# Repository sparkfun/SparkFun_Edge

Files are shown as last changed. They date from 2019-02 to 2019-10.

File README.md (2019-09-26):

SparkFun Edge 2
========================================

SparkFun Edge 2

[*SparkFun Edge 2 (DEV-15420)*](https://www.sparkfun.com/products/15420)

Edge computing is here! You've probably heard of this latest entry to the long lineage of tech buzzwords like "IoT," "LoRa," and "cloud" before it, but what is “the edge” and why does it matter? The cloud is impressively powerful but all-the-time connection requires power and connectivity that may not be available. Edge computing handles discrete tasks such as determining if someone said "yes" and responds accordingly. The audio analysis is done at the edge rather than on the web. This dramatically reduces costs and complexity while limiting potential data privacy leaks.

In collaboration with Google and Ambiq, SparkFun's Edge 2 Development Board is based around the newest edge technology and is perfect for getting your feet wet with voice and even gesture recognition without relying on the distant services of other companies. The truly special feature is in the utilization of SparkFun's open-source and FCC Certified Artemis module, whose ultra-efficient ARM Cortex-M4F 48MHz (with 96MHz burst mode) processor, is spec’d to run TensorFlow Lite using only 6uA/MHz. The SparkFun Edge 2 board currently measures ~1.6mA@3V and 48MHz and can run solely on a CR2032 coin cell battery for up to 10 days. Artemis sports all the cutting edge features expected of modern microcontrollers including six configurable I2C/SPI masters, two UARTs, one I2C/SPI slave, a 15-channel 14-bit ADC, and a dedicated Bluetooth processor that supports BLE5. On top of all that the Artemis has 1MB of flash and 384KB of SRAM memory - plenty for the vast majority of applications.

On the Edge 2 you'll have built-in access to sensors, Bluetooth, I2C expansion, and GPIO inputs/outputs. To support edge computing cases like voice recognition the Edge 2 board features two MEMS microphones, an ST LIS2DH12 3-axis accelerometer on its own I2C bus, and a connector to interface to an OV7670 camera (sold separately & functionality coming soon). As TensorFlow updates their algorithms more and more features will open up for the SparkFun Edge 2. An onboard Bluetooth antenna gives the Edge 2 out-of-the-box connectivity. Also available on the board is a Qwiic connector to add I2C sensors/devices, four LEDs, and four GPIO pins. To boast the low-power capabilities of the board we've outfitted it with battery operation from the CR2032 coin cell holder. Programming the board is taken care of with an external USB-serial adapter like the Serial Basic Breakout via a serial bootloader, but for more advanced users we've also made available the JTAG programming and debugger port.

As a brave explorer of this new technology, you'll have to use some advanced concepts but don't worry. Between Ambiq Micro's Software Development Kit and our SDK Setup Guide you'll have access to plenty of examples to begin working with your hardware.

Now get out there and make something amazing with the latest machine learning technology at your very own fingertips!

Repository Contents
-------------------

* **/Documentation** - Data sheets, additional product information
* **/Firmware** - Arduino test firmware sketch
* **/Hardware** - Eagle design files (.brd, .sch)
* **/Production** - Production panel files (.brd)

Documentation
--------------
* **[Board Support Package (BSP)](https://github.com/sparkfun/SparkFun_Edge_BSP)** - Ambiq SDK Board Support Package for the SparkFun Edge.
* **[Edge Board Hookup Guide](https://learn.sparkfun.com/tutorials/sparkfun-edge-hookup-guide)** - Basic hookup guide for the SparkFun Edge.
* **[Software Development Kit (SDK) Setup Guide](https://learn.sparkfun.com/tutorials/using-sparkfun-edge-board-with-ambiq-apollo3-sdk)** - Software Development Kit for working with the SparkFun Edge.

Product Versions
----------------
* [DEV-15420](https://www.sparkfun.com/products/15420)- SparkFun Edge 2 w/ Artemis Module
* [DEV-15170](https://www.sparkfun.com/products/15170)- SparkFun Edge

Version History
---------------
* [v20](https://github.com/sparkfun/SparkFun_Edge/tree/v2.0.0) - Edge with the Artemis
* [v10](https://github.com/sparkfun/SparkFun_Edge/tree/v10) - Initial HW release

License Information
-------------------

This product is _**open source**_! 

Please review the LICENSE.md file for license information. 

If you have any questions or concerns on licensing, please contact techsupport@sparkfun.com.

Distributed as-is; no warranty is given.

- Your friends at SparkFun.

_<COLLABORATION CREDIT>_

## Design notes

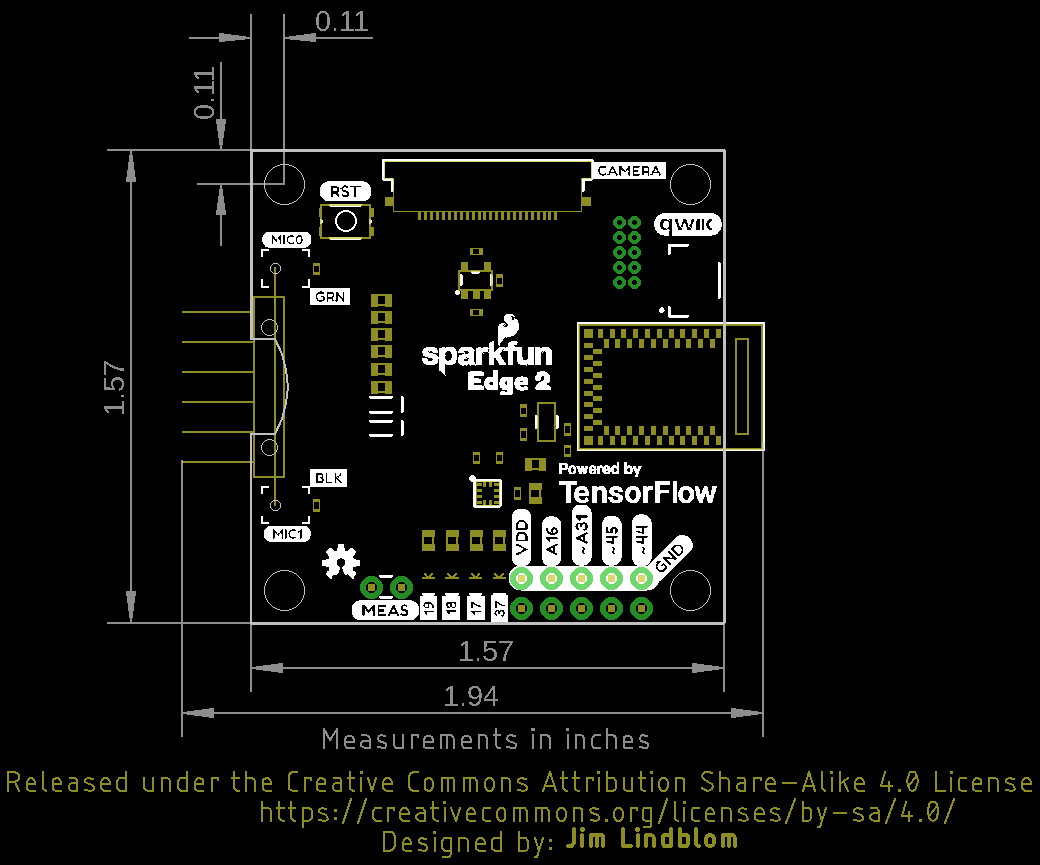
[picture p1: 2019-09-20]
Documentation/SparkFun_Edge_2_Dimensions.png

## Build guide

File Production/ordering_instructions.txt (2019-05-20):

panel size, 157x135mm
PCB thickness, 1.6mm
number of layers, 4
soldermask color, Red
silkscreen color, White
oz copper, 1oz
finish, HASL lead free
stencils, top+bottom
pcs per panel, 9
min trace width, 0.127000mm / 0.005000in
min drill size, 0.200000mm / 0.007874in
filename to layer stackup 1/2/3/4: GTL, GL2, GL3, GBL
dill files: .TXT.0102 (connect GTL to GL2)
dill files: .TXT.0115 (connect GTL to GL3)
dill files: .TXT.0116 (connect GTL to GBL)

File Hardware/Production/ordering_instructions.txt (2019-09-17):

panel size, 170x135mm
PCB thickness, 1.6mm
number of layers, 2
soldermask color, Red
silkscreen color, White
oz copper, 1oz
finish, HASL lead free
stencils, top+bottom
pcs per panel, 9
min trace width, 0.152400mm / 0.006000in
min drill size, 0.304800mm / 0.012000in

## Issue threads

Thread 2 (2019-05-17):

No MPN for 1.8V regulator on PDF schematic

cHemingway, 2019-05-17:
The 1.8V regulator, U3, does not have a part number written next to it.

I was interested to know what it was to estimate the power consumption, as it is always powered, though with disabled output by default.

nseidle, 2019-05-17:
Np. AP2127K-1.8TRG1. [Datasheet](https://www.diodes.com/assets/Datasheets/AP2127.pdf). Quiescent current looks to be 60µA.

cHemingway, 2019-05-17:
Thanks!

Closed 2019-05-17.

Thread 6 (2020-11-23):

Using Sparkfun BLE Radio for transmitting data

sleebapaul, 2020-11-23:
### Subject of the issue
I looked hard on finding a library that enables BLE communication with Sparkfun Edge. I found some Arduino libraries like `BLEPeripheral` but none of them did the job. Couldn't find any official reference for the topic either. Can somebody shed some light on this issue?

### Workbench
* Platform: Sparkfun Edge connected to MacBook Pro 2018.
* Device is powered using standard USB thorough SparkFun Serial Basic Breakout.
* I've run a micro speech example on the board and it worked well.

### Configuration

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

### Error while compiling with `BLEPeripheral` library.

```
Error while detecting libraries included by /*/*/*/Arduino/libraries/BLEPeripheral/src/BLECentral.cpp
Error while detecting libraries included by /*/*/*/Arduino/libraries/BLEPeripheral/src/EddystoneBeacon.cpp

In file included from /*/*/*/Arduino/libraries/BLEPeripheral/src/utility/lib_aci.h:34,
                 from /*/*/*/Arduino/libraries/BLEPeripheral/src/nRF8001.h:9,
                 from /*/*/*/Arduino/libraries/BLEPeripheral/src/BLEPeripheral.h:26,
                 from /*/*/*/Arduino/blutooth/blutooth.ino:3:
/*/*/*/Arduino/libraries/BLEPeripheral/src/utility/hal_platform.h:75:6: error: #error "Unsupported platform"
     #error "Unsupported platform"
```

sleebapaul, 2021-01-29:
It is so unfortunate to see the cold response from the company that built this board. A lot of enthusiasts like me, buy a SparkFun board, thinking there will be support from the community.  I'm terribly mistaken. I could've bought Arduino Nano BLE 33 and life would've been easy. Never again. Bye, SparkFun.

Closed 2021-01-29.

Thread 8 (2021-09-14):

Default Firmware

lungualexandru, 2021-09-14:
### Subject of the issue
I erased the board with a J-link programmer and haven't found the original bootloader/firmware which comes with the board.
I was wondering whether you could upload it here so that i could re-flash the board to its initial functionality.

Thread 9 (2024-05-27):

No reponse error

h-tye, 2024-05-27:
Hello, I am facing the same issue as the one referenced below. I have taken the necessary steps to ensure that the driver is not causing issues. I have also tried making my baud rate 115200. I am on Ubuntu 22.04. Any tips on how to get around this?

  All, just got my new SparkFun Edge, trying to build and flash test program, build is OK, but flashing failed.

I'm using Ubuntu 19.10. I've followed this link https://learn.sparkfun.com/tutorials/how-to-install-ch340-drivers/all#linux

So CH341 driver issue is not a problem, after plugin the USB serial to my PC, dmesg shows:

[66495.174916] usb 1-1.2: new full-speed USB device number 23 using ehci-pci
[66495.284880] usb 1-1.2: New USB device found, idVendor=1a86, idProduct=7523, bcdDevice= 2.64
[66495.284885] usb 1-1.2: New USB device strings: Mfr=0, Product=2, SerialNumber=0
[66495.284888] usb 1-1.2: Product: USB Serial
[66495.285859] ch34x 1-1.2:1.0: ch34x converter detected
[66495.287652] usb 1-1.2: ch34x converter now attached to ttyUSB3

Following this step, https://learn.sparkfun.com/tutorials/using-sparkfun-edge-board-with-ambiq-apollo3-sdk/, I tried to flash Code to Board

$ make bootload
../../../../../tools/apollo3_scripts/create_cust_image_blob.py --bin bin/example1_edge_test.bin --load-address 0xC000 --magic-num 0xCB -o bin/main_nonsecure_ota --version 0x0
Header Size =  0x80
original app_size  0x4a98 ( 19096 )
load_address  0xc000 ( 49152 )
app_size  0x4a98 ( 19096 )
w0 = 0xcb004b18
Security Value  0x10
w2 =  0x10008080
addrWord =  0xc000
versionKeyWord =  0x0
child0/feature =  0xffffffff
child1 =  0xffffffff
crc =   0xbf984a8b
Writing to file  bin/main_nonsecure_ota.bin
../../../../../tools/apollo3_scripts/create_cust_wireupdate_blob.py --load-address 0x20000 --bin bin/main_nonsecure_ota.bin -i 6 -o bin/main_nonsecure_wire --options 0x1
Header Size =  0x60
app_size  0x4b18 ( 19224 )
Writing to file  bin/main_nonsecure_wire.bin
Image from  0x0  to  0x4b18  will be loaded at 0x20000
../../../bsp/tools/uart_wired_update_sparkfun.py -b 921600 /dev/ttyUSB3 -r 1 -f bin/main_nonsecure_wire.bin -i 6
Connecting with Corvette over serial port /dev/ttyUSB3...
Sending Hello.
No response for command 0x00000000
Traceback (most recent call last):
  File "../../../bsp/tools/uart_wired_update_sparkfun.py", line 343, in <module>
    main()
  File "../../../bsp/tools/uart_wired_update_sparkfun.py", line 44, in main
    connect_device(ser)
  File "../../../bsp/tools/uart_wired_update_sparkfun.py", line 63, in connect_device
    response = send_command(hello, 88, ser)
  File "../../../bsp/tools/uart_wired_update_sparkfun.py", line 240, in send_command
    raise NoResponseError
__main__.NoResponseError
make: *** [Makefile:197: bootload] Error 1

_Originally posted by @neilengineer in https://github.com/sparkfun/SparkFun_Edge_BSP/issues/3#issuecomment-618831768_

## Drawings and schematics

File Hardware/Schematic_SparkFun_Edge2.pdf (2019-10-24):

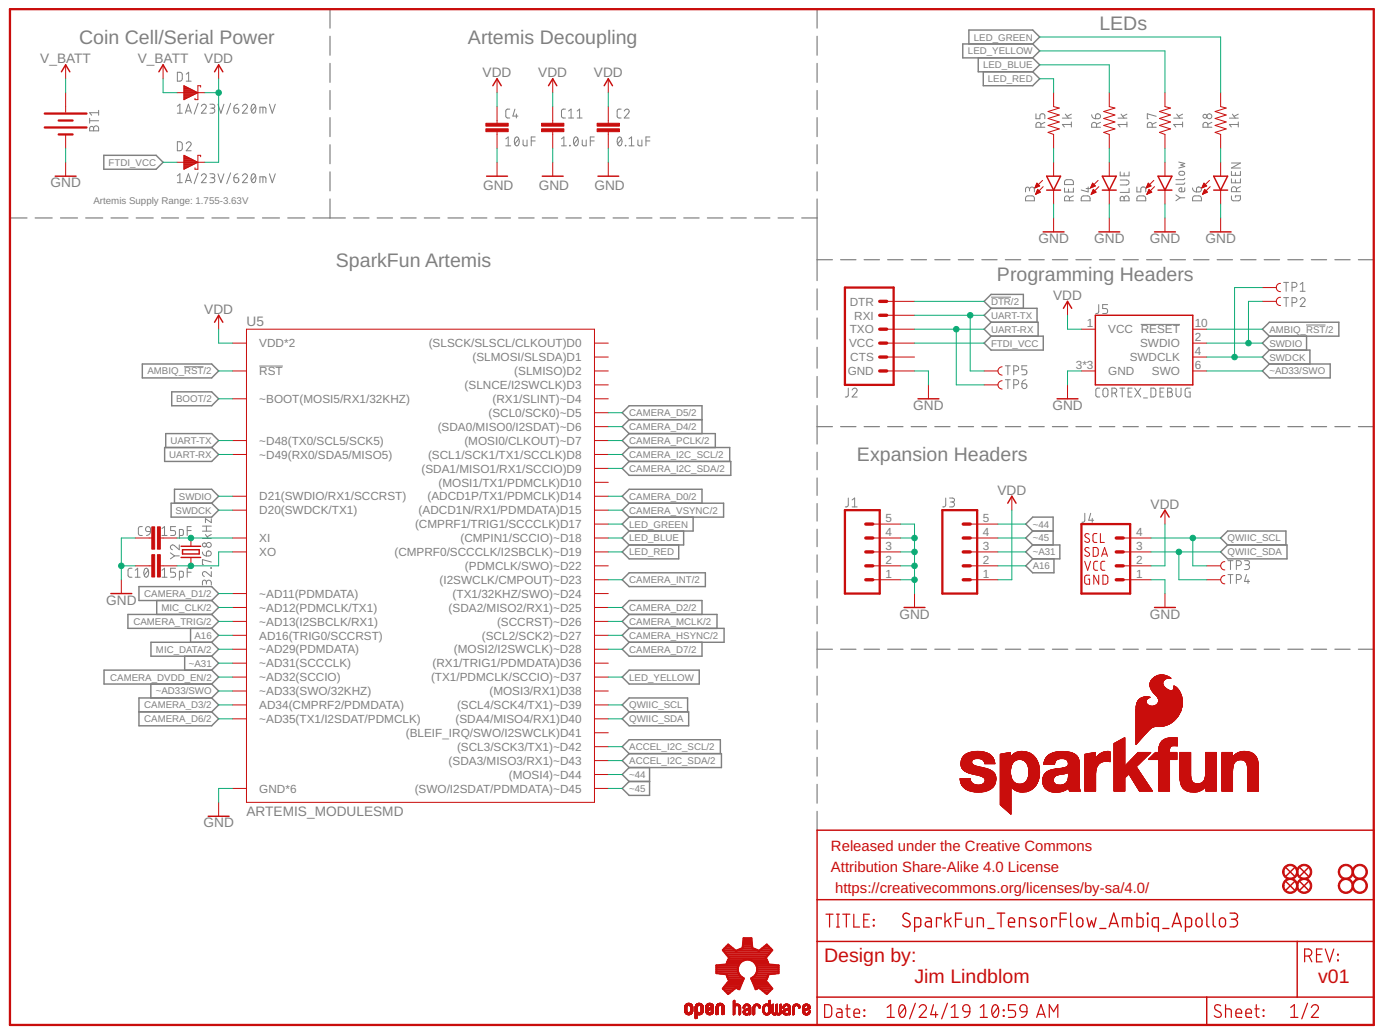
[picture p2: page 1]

~BOOT(MOSI5/RX1/32KHZ) D21(SWDIO/RX1/SCCRST) D20(SWDCK/TX1)

~AD11(PDMDATA) ~AD12(PDMCLK/TX1) ~AD13(I2SBCLK/RX1) AD16(TRIG0/SCCRST) ~AD29(PDMDATA) ~AD31(SCCCLK) ~AD32(SCCIO) AD34(CMPRF2/PDMDATA) ~AD35(TX1/I2SDAT/PDMCLK)

Released under the Creative Commons Attribution Share-Alike 4.0 License

https://creativecommons.org/licenses/by-sa/4.0/

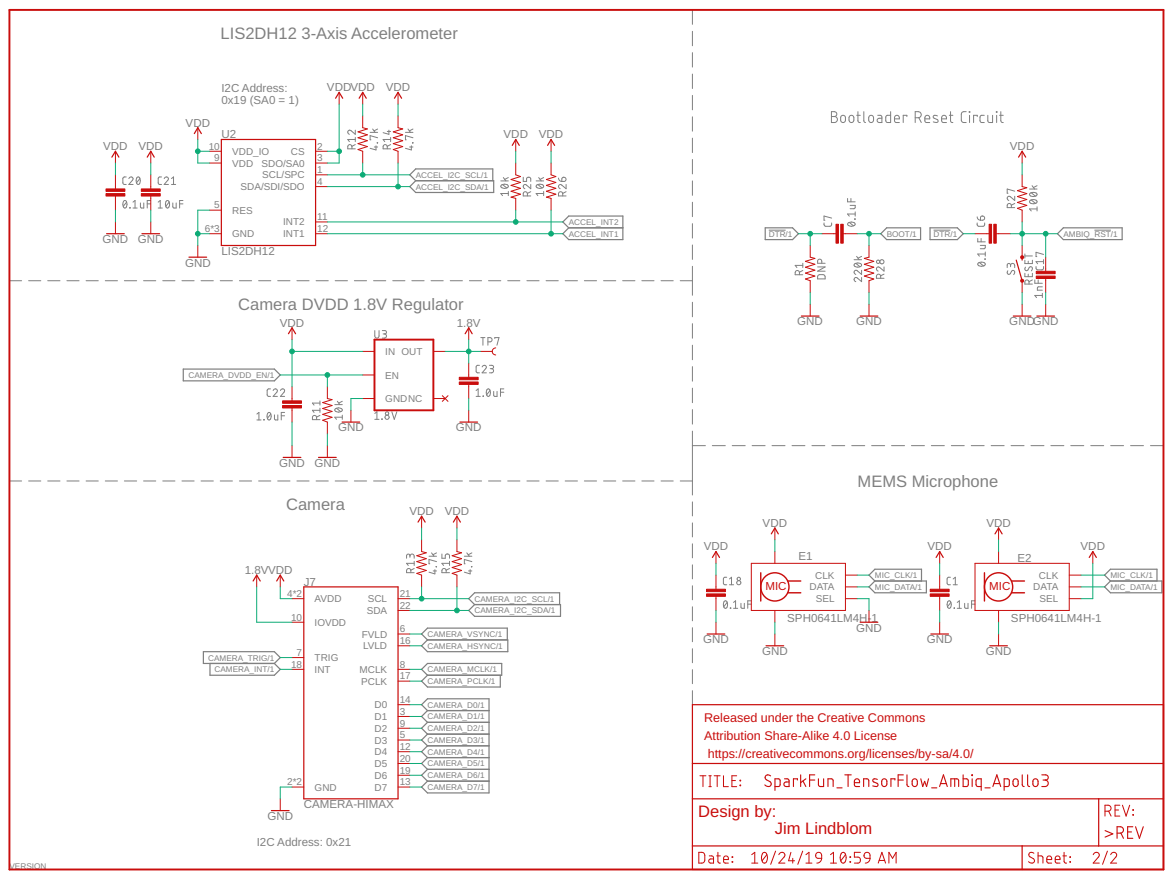
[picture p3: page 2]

Released under the Creative Commons Attribution Share-Alike 4.0 License

https://creativecommons.org/licenses/by-sa/4.0/

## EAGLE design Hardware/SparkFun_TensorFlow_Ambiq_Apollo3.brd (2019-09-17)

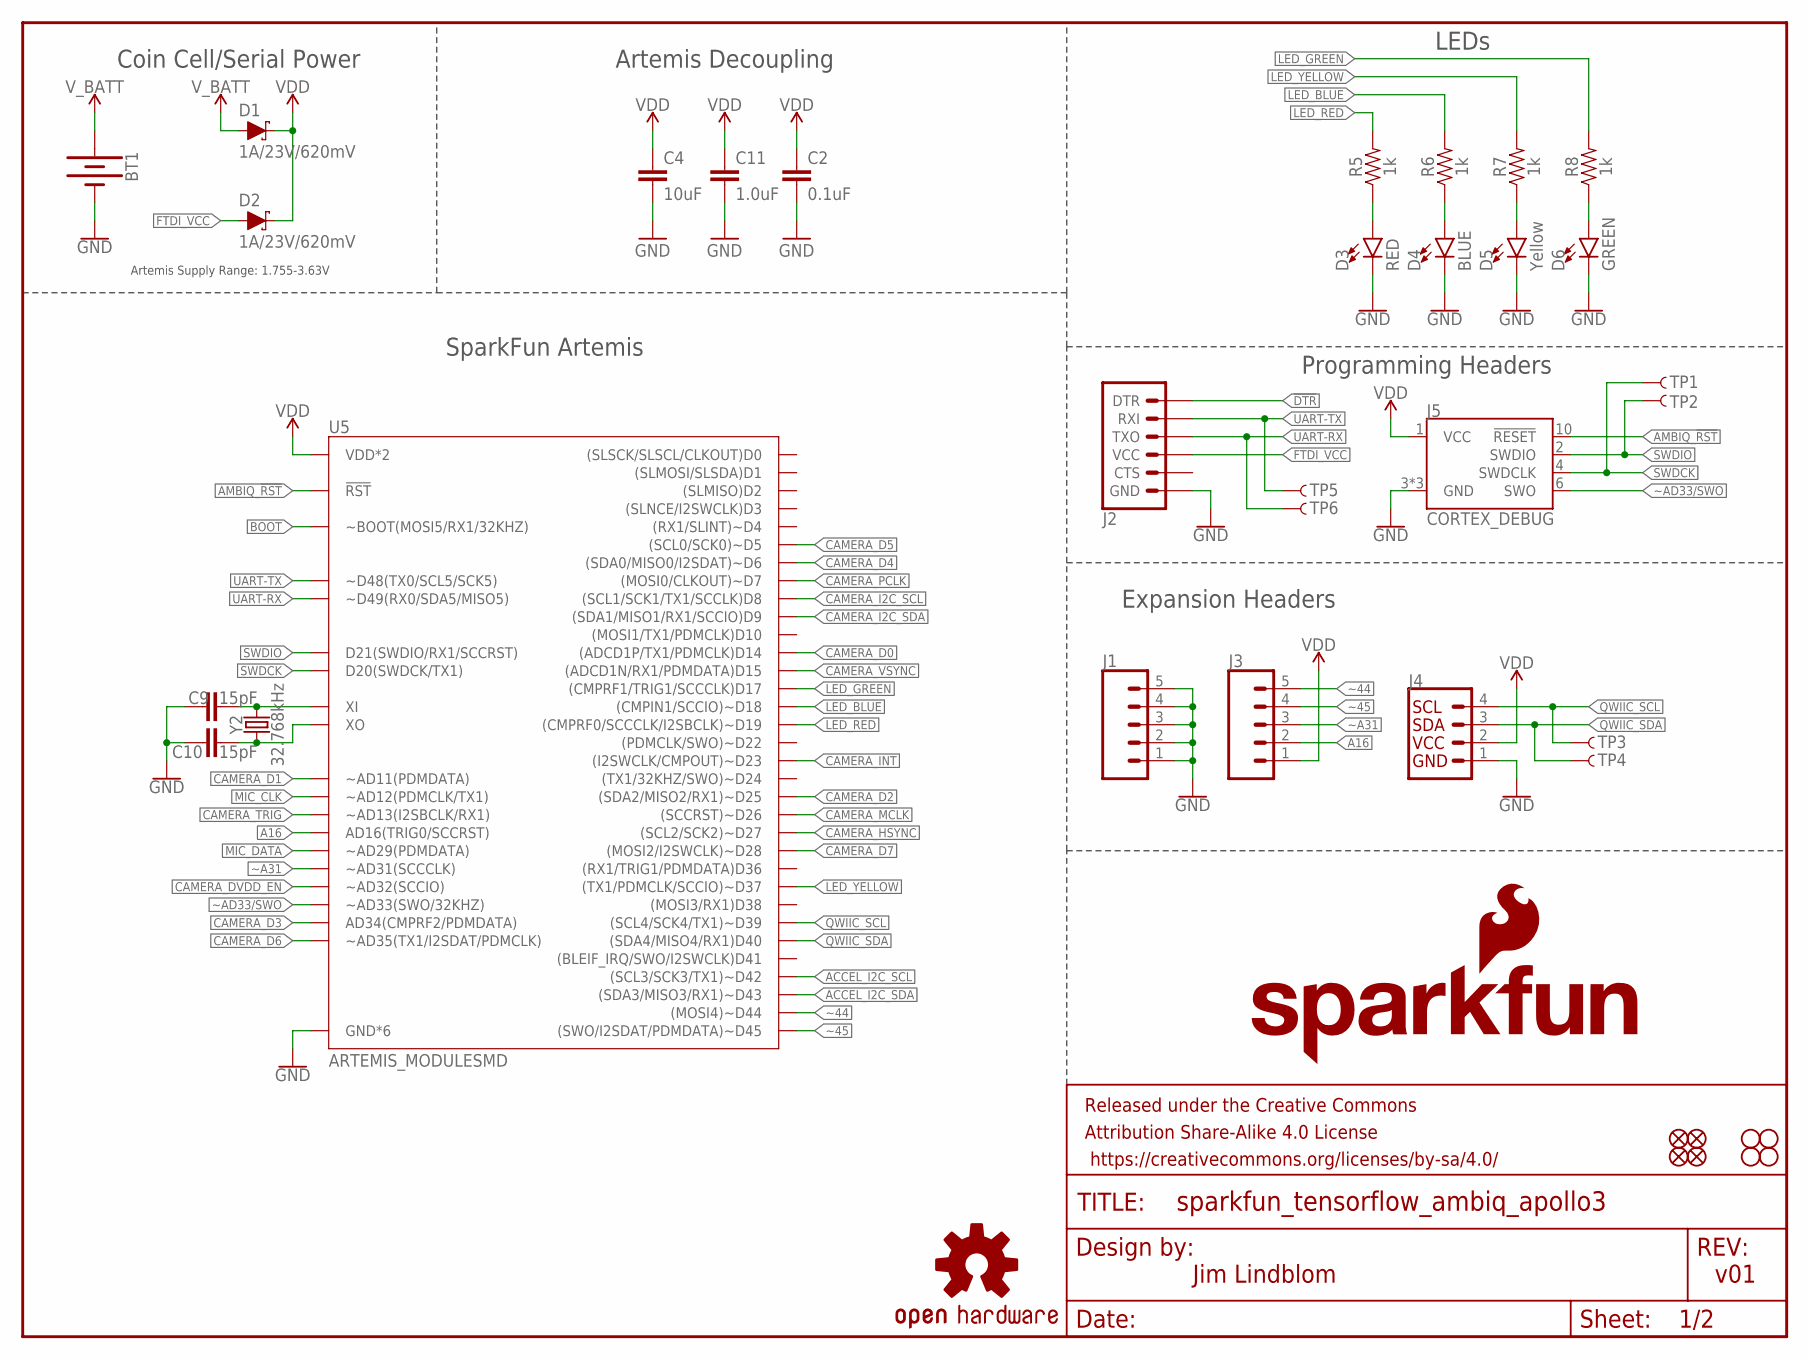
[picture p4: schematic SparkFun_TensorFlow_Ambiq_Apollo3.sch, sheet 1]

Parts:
BT1: BATTERY-20MM_SMD_4LEGS_OVERPASTE_INNER; BATTCON_20MM_4LEGS_OVERPASTE_INNER
C2: 0.1uF; 0402-TIGHT
C4: 10uF; 0603
C9, C10: 15pF; 0402-TIGHT
C11: 1.0uF; 0402-TIGHT
D1, D2: 1A/23V/620mV; SOD-323
D3: RED; LED-0603
D4: BLUE; LED-0603
D5: Yellow; LED-0603
D6: GREEN; LED-0603
FD1, FD2, FD3, FD4: FIDUCIAL1X2; FIDUCIAL-1X2
FRAME1: FRAME-LETTER; CREATIVE_COMMONS
H1, H2, H3, H4: STAND-OFF
J1, J3: CONN_05NO_SILK; 1X05_NO_SILK
J2: 6_PIN_SERIAL_TARGETSMD; 1X06-SMD_RA_MALE
J4: QWIIC_CONNECTORJS-1MM; JST04_1MM_RA
J5: CORTEX_DEBUG; 2X5-PTH-1.27MM
LOGO1: SFE_LOGO_NAME_FLAME.1_INCH; SFE_LOGO_NAME_FLAME_.1
LOGO2: OSHW-LOGOS; OSHW-LOGO-S
R5, R6, R7, R8: 1k; 0603
TP1, TP2, TP3, TP4, TP5, TP6: TEST-POINT3X5; PAD.03X.05
U5: ARTEMIS_MODULESMD; ARTEMIS_FP
Y2: 32.768kHz; CRYSTAL-SMD-3.2X1.5MM

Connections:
!DTR: J2.1 (DTR); also elsewhere on the board
A16: J3.2, U5.AD16 (AD16(TRIG0/SCCRST))
ACCEL_I2C_SCL: U5.~D42 ((SCL3/SCK3/TX1)~D42); also elsewhere on the board
ACCEL_I2C_SDA: U5.~D43 ((SDA3/MISO3/RX1)~D43); also elsewhere on the board
AMBIQ_!RST: J5.10 (!RESET), U5.~RST (!RST); also elsewhere on the board
BOOT: U5.BOOT (~BOOT(MOSI5/RX1/32KHZ)); also elsewhere on the board
CAMERA_D0: U5.D14 ((ADCD1P/TX1/PDMCLK)D14); also elsewhere on the board
CAMERA_D1: U5.~AD11 (~AD11(PDMDATA)); also elsewhere on the board
CAMERA_D2: U5.~D25 ((SDA2/MISO2/RX1)~D25); also elsewhere on the board
CAMERA_D3: U5.AD34 (AD34(CMPRF2/PDMDATA)); also elsewhere on the board
CAMERA_D4: U5.~D6 ((SDA0/MISO0/I2SDAT)~D6); also elsewhere on the board
CAMERA_D5: U5.~D5 ((SCL0/SCK0)~D5); also elsewhere on the board
CAMERA_D6: U5.~AD35 (~AD35(TX1/I2SDAT/PDMCLK)); also elsewhere on the board
CAMERA_D7: U5.~D28 ((MOSI2/I2SWCLK)~D28); also elsewhere on the board
CAMERA_DVDD_EN: U5.~AD32 (~AD32(SCCIO)); also elsewhere on the board
CAMERA_HSYNC: U5.~D27 ((SCL2/SCK2)~D27); also elsewhere on the board
CAMERA_I2C_SCL: U5.D8 ((SCL1/SCK1/TX1/SCCLK)D8); also elsewhere on the board
CAMERA_I2C_SDA: U5.D9 ((SDA1/MISO1/RX1/SCCIO)D9); also elsewhere on the board
CAMERA_INT: U5.~D23 ((I2SWCLK/CMPOUT)~D23); also elsewhere on the board
CAMERA_MCLK: U5.~D26 ((SCCRST)~D26); also elsewhere on the board
CAMERA_PCLK: U5.D7 ((MOSI0/CLKOUT)~D7); also elsewhere on the board
CAMERA_TRIG: U5.~AD13 (~AD13(I2SBCLK/RX1)); also elsewhere on the board
CAMERA_VSYNC: U5.D15 ((ADCD1N/RX1/PDMDATA)D15); also elsewhere on the board
FTDI_VCC: D2.A, J2.4 (VCC)
GND: BT1.2 (-), C2.1, C4.2, C9.1, C10.1, C11.2, D3.C, D4.C, D5.C, D6.C, J1.1, J1.2, J1.3, J1.4, J1.5, J2.6 (GND), J4.1, J5.3 (GND), J5.5 (GND), J5.9 (GND), U5.GND@1 (GND*6), U5.GND@22 (GND*6), U5.GND@38 (GND*6), U5.GND@39 (GND*6), U5.GND@47 (GND*6), U5.GND@59 (GND*6); also elsewhere on the board
LED_BLUE: R6.2, U5.~D18 ((CMPIN1/SCCIO)~D18)
LED_GREEN: R8.2, U5.D17 ((CMPRF1/TRIG1/SCCCLK)D17)
LED_RED: R5.2, U5.~D19 ((CMPRF0/SCCCLK/I2SBCLK)~D19)
LED_YELLOW: R7.2, U5.~D37 ((TX1/PDMCLK/SCCIO)~D37)
MIC_CLK: U5.~AD12 (~AD12(PDMCLK/TX1)); also elsewhere on the board
MIC_DATA: U5.~AD29 (~AD29(PDMDATA)); also elsewhere on the board
unnamed: C9.2, U5.XI, Y2.P$2 (2)
unnamed: D4.A, R6.1
unnamed: D3.A, R5.1
unnamed: D5.A, R7.1
unnamed: D6.A, R8.1
QWIIC_SCL: J4.4, TP3.P$1, U5.~D39 ((SCL4/SCK4/TX1)~D39)
QWIIC_SDA: J4.3, TP4.P$1, U5.D40 ((SDA4/MISO4/RX1)D40)
SWDCK: J5.4 (SWDCLK), TP1.P$1, U5.SWDCK (D20(SWDCK/TX1))
SWDIO: J5.2 (SWDIO), TP2.P$1, U5.SWDIO (D21(SWDIO/RX1/SCCRST))
UART-RX: J2.3 (TXO), TP6.P$1, U5.RXI-0 (~D49(RX0/SDA5/MISO5))
UART-TX: J2.2 (RXI), TP5.P$1, U5.TXO-0 (~D48(TX0/SCL5/SCK5))
VDD: C2.2, C4.1, C11.1, D1.C, D2.C, J3.1, J4.2, J5.1 (VCC), U5.VDD@36 (VDD*2), U5.VDD@37 (VDD*2); also elsewhere on the board
V_BATT: BT1.1 (+), D1.A
X0: C10.2, U5.XO, Y2.P$1 (1)
~44: J3.5, U5.~D44 ((MOSI4)~D44)
~45: J3.4, U5.~D45 ((SWO/I2SDAT/PDMDATA)~D45)
~A31: J3.3, U5.~AD31 (~AD31(SCCCLK))
~AD33/SWO: J5.6 (SWO), U5.~AD33/SWO (~AD33(SWO/32KHZ))

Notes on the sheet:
v01
Jim Lindblom
Artemis Supply Range: 1.755-3.63V
SparkFun Artemis
Coin Cell/Serial Power
Artemis Decoupling
LEDs
Programming Headers
Expansion Headers

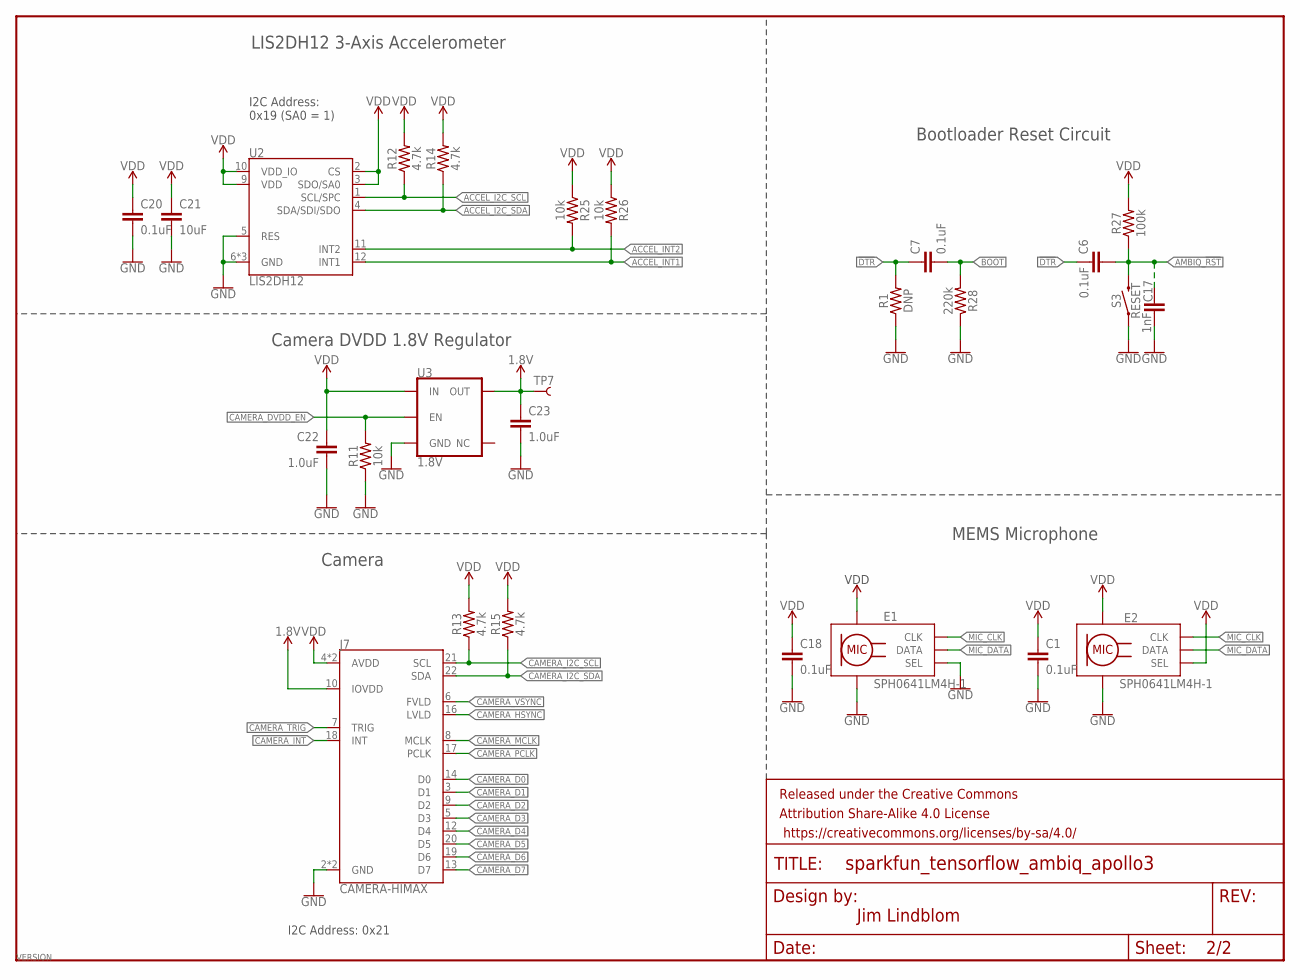
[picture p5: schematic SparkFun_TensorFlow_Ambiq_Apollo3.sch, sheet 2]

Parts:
C1, C18, C20: 0.1uF; 0402-TIGHT
C6, C7: 0.1uF; 0603
C17: 1nF; 0603
C21: 10uF; 0603
C22, C23: 1.0uF; 0402-TIGHT
E1, E2: SPH0641LM4H-1; SPH0641LM4H-1_MICROPHONE
FRAME2: FRAME-LETTERNO_PACKAGE; DUMMY
J7: CAMERA-HIMAX; FPC-24-AMPHENOL-SFV24R-1STE1HLF
R1: DNP; 0603
R11, R25, R26: 10k; 0402-TIGHT
R12, R13, R14, R15: 4.7k; 0603
R27: 100k; 0603
R28: 220k; 0603
S3: RESET; TACTILE_SWITCH_SMD_4.6X2.8MM
TP7: TEST-POINT3X5; PAD.03X.05
U2: LIS2DH12; LGA-12-LISDH12
U3: 1.8V; SOT23-5

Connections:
1.8V: C23.1, J7.10 (IOVDD), TP7.P$1, U3.5 (OUT)
!DTR: C6.1, C7.1, R1.2; also elsewhere on the board
ACCEL_I2C_SCL: R12.1, U2.1 (SCL/SPC); also elsewhere on the board
ACCEL_I2C_SDA: R14.1, U2.4 (SDA/SDI/SDO); also elsewhere on the board
ACCEL_INT1: R26.2, U2.12 (INT1)
ACCEL_INT2: R25.2, U2.11 (INT2)
AMBIQ_!RST: C6.2, C17.1, R27.1, S3.3 (2), S3.4 (2); also elsewhere on the board
BOOT: C7.2, R28.2; also elsewhere on the board
CAMERA_D0: J7.14 (D0); also elsewhere on the board
CAMERA_D1: J7.3 (D1); also elsewhere on the board
CAMERA_D2: J7.9 (D2); also elsewhere on the board
CAMERA_D3: J7.5 (D3); also elsewhere on the board
CAMERA_D4: J7.12 (D4); also elsewhere on the board
CAMERA_D5: J7.20 (D5); also elsewhere on the board
CAMERA_D6: J7.19 (D6); also elsewhere on the board
CAMERA_D7: J7.13 (D7); also elsewhere on the board
CAMERA_DVDD_EN: R11.2, U3.3 (EN); also elsewhere on the board
CAMERA_HSYNC: J7.16 (LVLD); also elsewhere on the board
CAMERA_I2C_SCL: J7.21 (SCL), R13.1; also elsewhere on the board
CAMERA_I2C_SDA: J7.22 (SDA), R15.1; also elsewhere on the board
CAMERA_INT: J7.18 (INT); also elsewhere on the board
CAMERA_MCLK: J7.8 (MCLK); also elsewhere on the board
CAMERA_PCLK: J7.17 (PCLK); also elsewhere on the board
CAMERA_TRIG: J7.7 (TRIG); also elsewhere on the board
CAMERA_VSYNC: J7.6 (FVLD); also elsewhere on the board
GND: C1.2, C17.2, C18.2, C20.2, C21.2, C22.2, C23.2, E1.2 (SEL), E1.3 (GND), E1.6 (GND), E1.7 (GND), E1.8 (GND), E2.3 (GND), E2.6 (GND), E2.7 (GND), E2.8 (GND), J7.2 (GND), J7.15 (GND), R1.1, R11.1, R28.1, S3.1, S3.2 (1), U2.5 (RES), U2.6 (GND), U2.7 (GND), U2.8 (GND), U3.2 (GND); also elsewhere on the board
MIC_CLK: E1.4 (CLK), E2.4 (CLK); also elsewhere on the board
MIC_DATA: E1.1 (DATA), E2.1 (DATA); also elsewhere on the board
VDD: C1.1, C18.1, C20.1, C21.1, C22.1, E1.5 (VDD), E2.2 (SEL), E2.5 (VDD), J7.4 (AVDD), J7.11 (AVDD), R12.2, R13.2, R14.2, R15.2, R25.1, R26.1, R27.2, U2.2 (CS), U2.3 (SDO/SA0), U2.9 (VDD), U2.10 (VDD_IO), U3.1 (IN); also elsewhere on the board

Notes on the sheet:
Camera DVDD 1.8V Regulator
LIS2DH12 3-Axis Accelerometer
Jim Lindblom
I2C Address: 0x19 (SA0 = 1)
I2C Address: 0x21
Camera
MEMS Microphone
Bootloader Reset Circuit

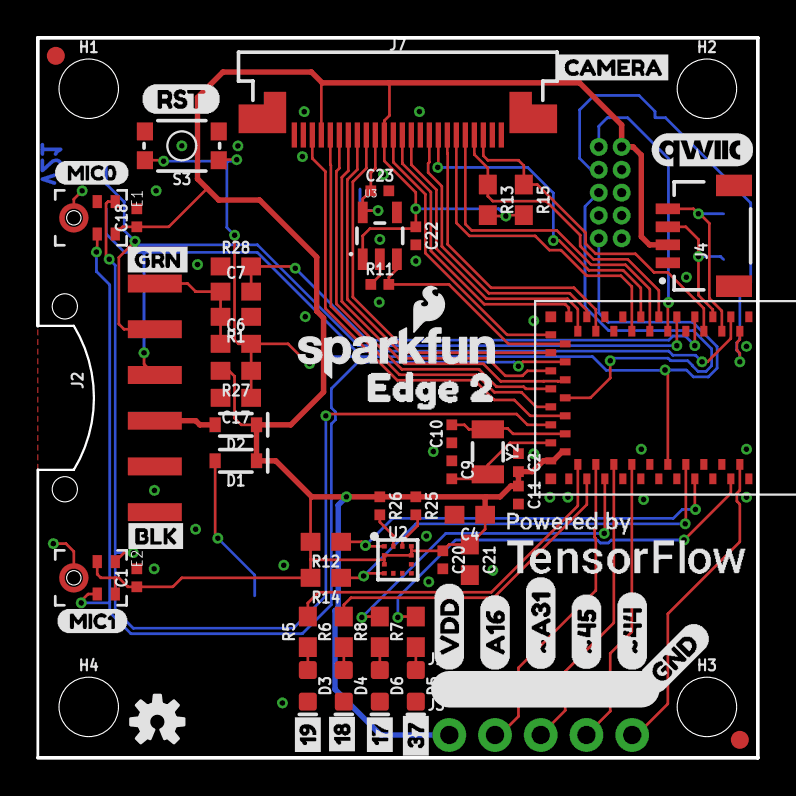
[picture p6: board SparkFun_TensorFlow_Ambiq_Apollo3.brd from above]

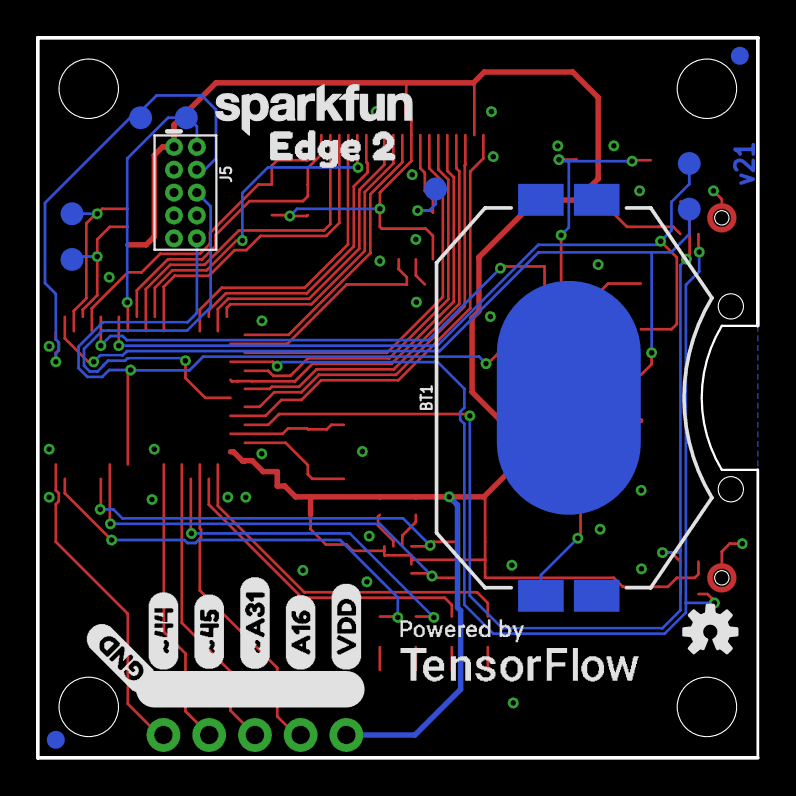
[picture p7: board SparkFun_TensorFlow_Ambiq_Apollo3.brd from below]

Board: 2 copper layers, 40.0 x 40.0 mm, 96 parts (21 on the bottom side), 52 nets.

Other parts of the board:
U$1: MIC00
U$2: BLK2
U$3, U$14: GND0
U$4, U$9: VDD1
U$5, U$12: #453
U$6, U$11: #A312
U$7, U$10: A161
U$8: MIC10
U$13, U$36: #444
U$15, U$32: EDGE_20
U$16: 372
U$19: QWIIC_COPYRIGHT_SMALL
U$20: CAMERA3
U$21, U$25: POWEREDBY_TF#JPG
U$23: 171
U$26: 182
U$27: RST15
U$28: GRN1
U$29: SFE_LOGO_NAME_.1
U$30: OSHW-LOGO-S
U$31: 193

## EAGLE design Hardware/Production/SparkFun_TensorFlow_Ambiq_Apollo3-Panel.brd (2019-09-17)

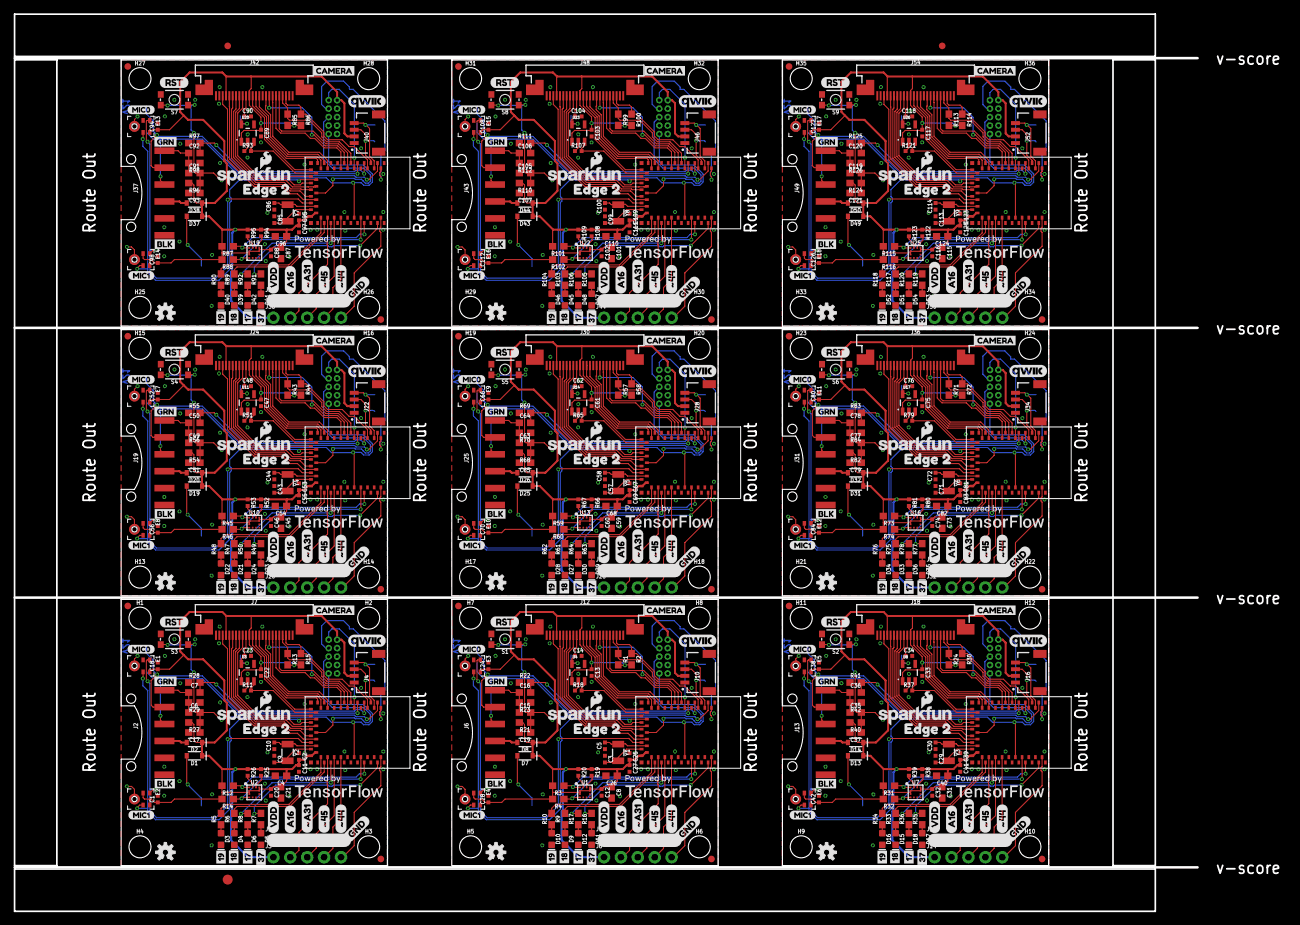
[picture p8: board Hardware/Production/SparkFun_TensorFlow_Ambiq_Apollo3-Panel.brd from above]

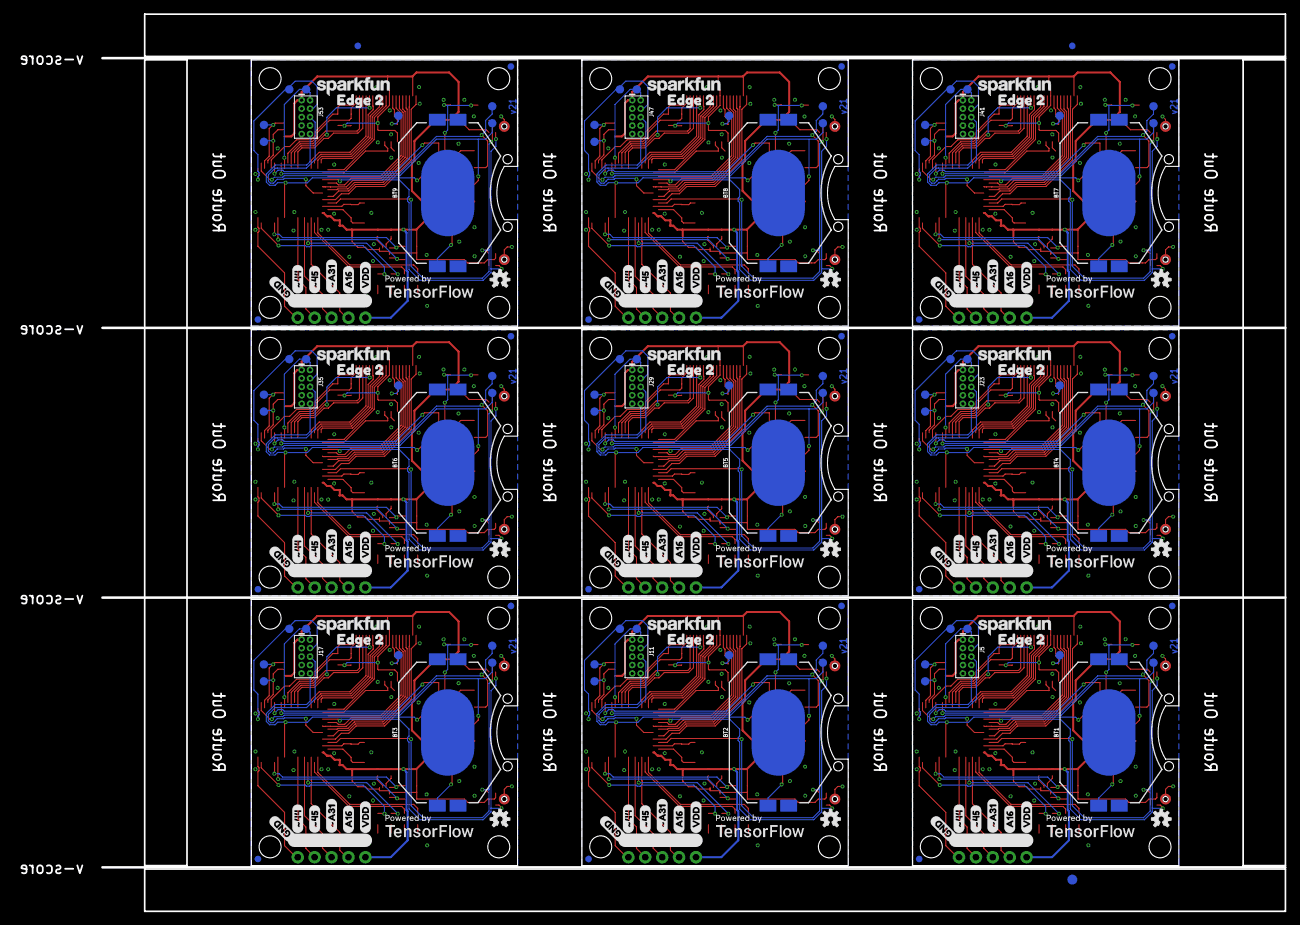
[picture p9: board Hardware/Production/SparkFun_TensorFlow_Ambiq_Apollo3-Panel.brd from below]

Board: 2 copper layers, 177.7 x 134.7 mm, 870 parts (192 on the bottom side), 468 nets.

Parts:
BT1, BT2, BT3, BT4, BT5, BT6, BT7, BT8, BT9: BATTCON_20MM_4LEGS_OVERPASTE_INNER
C1, C2, C12, C18, C20, C24, C25, C28, C32, C38, C39, C42, C46, C52, C53, C56, C60, C66, C67, C70, C74, C80, C81, C84, C88, C94, C95, C98, C102, C108, C109, C112, C116, C122, C123, C126: 0.1uF; 0402-TIGHT
C3, C5, C9, C10, C29, C30, C43, C44, C57, C58, C71, C72, C85, C86, C99, C100, C113, C114: 15pF; 0402-TIGHT
C4, C8, C21, C26, C31, C40, C45, C54, C59, C68, C73, C82, C87, C96, C101, C110, C115, C124: 10uF; 0603
C6, C15, C35, C49, C63, C77, C91, C105, C119: 0.1uF; 0603
C7, C16, C36, C50, C64, C78, C92, C106, C120: 2.2uF; 0603
C11, C13, C14, C22, C23, C27, C33, C34, C41, C47, C48, C55, C61, C62, C69, C75, C76, C83, C89, C90, C97, C103, C104, C111, C117, C118, C125: 1.0uF; 0402-TIGHT
C17, C19, C37, C51, C65, C79, C93, C107, C121: 1nF; 0603
D1, D2, D7, D8, D13, D14, D19, D20, D25, D26, D31, D32, D37, D38, D43, D44, D49, D50: 1A/23V/620mV; SOD-323
D3, D10, D16, D22, D28, D34, D40, D46, D52: RED; LED-0603
D4, D9, D15, D21, D27, D33, D39, D45, D51: BLUE; LED-0603
D5, D11, D17, D23, D29, D35, D41, D47, D53: Yellow; LED-0603
D6, D12, D18, D24, D30, D36, D42, D48, D54: GREEN; LED-0603
E1, E2, E3, E4, E5, E6, E7, E8, E9, E10, E11, E12, E13, E14, E15, E16, E17, E18: SPH0641LM4H-1; SPH0641LM4H-1_MICROPHONE
E$1, E$2, E$3, E$4: FIDUCIAL-1X2
E$5, E$6: FIDUCIAL-1.5X3
FD1, FD2, FD3, FD4, FD5, FD6, FD7, FD8, FD9, FD10, FD11, FD12, FD13, FD14, FD15, FD16, FD17, FD18, FD19, FD20, FD21, FD22, FD23, FD24, FD25, FD26, FD27, FD28, FD29, FD30, FD31, FD32, FD33, FD34, FD35, FD36: FIDUCIAL1X2; FIDUCIAL-1X2
FRAME1, FRAME3, FRAME5, FRAME7, FRAME9, FRAME11, FRAME13, FRAME15, FRAME17: FRAME-LETTER; CREATIVE_COMMONS
FRAME2, FRAME4, FRAME6, FRAME8, FRAME10, FRAME12, FRAME14, FRAME16, FRAME18: FRAME-LETTERNO_PACKAGE; DUMMY
H1, H2, H3, H4, H5, H6, H7, H8, H9, H10, H11, H12, H13, H14, H15, H16, H17, H18, H19, H20, H21, H22, H23, H24, H25, H26, H27, H28, H29, H30, H31, H32, H33, H34, H35, H36: STAND-OFF
J1, J3, J8, J9, J14, J15, J20, J21, J26, J27, J32, J33, J38, J39, J44, J45, J50, J51: 1X05_NO_SILK
J2, J6, J13, J19, J25, J31, J37, J43, J49: 1X06-SMD_RA_MALE
J4, J10, J16, J22, J28, J34, J40, J46, J52: JST04_1MM_RA
J5, J11, J17, J23, J29, J35, J41, J47, J53: CORTEX_DEBUG; 2X5-PTH-1.27MM
J7, J12, J18, J24, J30, J36, J42, J48, J54: CAMERA-HIMAX; FPC-24-AMPHENOL-SFV24R-1STE1HLF
LOGO1, LOGO3, LOGO5, LOGO7, LOGO9, LOGO11, LOGO13, LOGO15, LOGO17: SFE_LOGO_NAME_FLAME.1_INCH; SFE_LOGO_NAME_FLAME_.1
LOGO2, LOGO4, LOGO6, LOGO8, LOGO10, LOGO12, LOGO14, LOGO16, LOGO18: OSHW-LOGOS; OSHW-LOGO-S
R1, R2, R3, R4, R12, R13, R14, R15, R24, R30, R31, R32, R43, R44, R45, R46, R57, R58, R59, R60, R71, R72, R73, R74, R85, R86, R87, R88, R99, R100, R101, R102, R113, R114, R115, R116: 4.7k; 0603
R5, R6, R7, R8, R9, R10, R16, R17, R33, R34, R35, R36, R47, R48, R49, R50, R61, R62, R63, R64, R75, R76, R77, R78, R89, R90, R91, R92, R103, R104, R105, R106, R117, R118, R119, R120: 1k; 0603
R11, R18, R19, R20, R25, R26, R37, R38, R39, R51, R52, R53, R65, R66, R67, R79, R80, R81, R93, R94, R95, R107, R108, R109, R121, R122, R123: 10k; 0402-TIGHT
R21, R23, R27, R29, R40, R42, R54, R56, R68, R70, R82, R84, R96, R98, R110, R112, R124, R126: 100k; 0603
R22, R28, R41, R55, R69, R83, R97, R111, R125: 10k; 0603
S1, S2, S3, S4, S5, S6, S7, S8, S9: RESET; TACTILE_SWITCH_SMD_4.6X2.8MM
TP1, TP2, TP8, TP9, TP15, TP16, TP22, TP23, TP29, TP30, TP36, TP37, TP43, TP44, TP50, TP51, TP57, TP58: PAD.03X.05
TP3, TP4, TP5, TP6, TP7, TP10, TP11, TP12, TP13, TP14, TP17, TP18, TP19, TP20, TP21, TP24, TP25, TP26, TP27, TP28, TP31, TP32, TP33, TP34, TP35, TP38, TP39, TP40, TP41, TP42, TP45, TP46, TP47, TP48, TP49, TP52, TP53, TP54, TP55, TP56, TP59, TP60, TP61, TP62, TP63: TEST-POINT3X5; PAD.03X.05
U1, U2, U7, U10, U13, U16, U19, U22, U25: LIS2DH12; LGA-12-LISDH12
U3, U4, U8, U11, U14, U17, U20, U23, U26: 1.8V; SOT23-5
U5, U6, U9, U12, U15, U18, U21, U24, U27: ARTEMIS_MODULESMD; ARTEMIS_FP
U$1, U$41, U$70, U$99, U$128, U$157, U$186, U$215, U$244: MIC00
U$2, U$34, U$64, U$93, U$122, U$151, U$180, U$209, U$238: BLK2
U$3, U$14, U$17, U$24, U$59, U$62, U$88, U$91, U$117, U$120, U$146, U$149, U$175, U$178, U$204, U$207, U$233, U$236: GND0
U$4, U$9, U$18, U$22, U$60, U$61, U$89, U$90, U$118, U$119, U$147, U$148, U$176, U$177, U$205, U$206, U$234, U$235: VDD1
U$5, U$12, U$46, U$52, U$75, U$81, U$104, U$110, U$133, U$139, U$162, U$168, U$191, U$197, U$220, U$226, U$249, U$255: #453
U$6, U$11, U$47, U$51, U$76, U$80, U$105, U$109, U$134, U$138, U$163, U$167, U$192, U$196, U$221, U$225, U$250, U$254: #A312
U$7, U$10, U$48, U$50, U$77, U$79, U$106, U$108, U$135, U$137, U$164, U$166, U$193, U$195, U$222, U$224, U$251, U$253: A161
U$8, U$49, U$78, U$107, U$136, U$165, U$194, U$223, U$252: MIC10
U$13, U$36, U$45, U$53, U$74, U$82, U$103, U$111, U$132, U$140, U$161, U$169, U$190, U$198, U$219, U$227, U$248, U$256: #444
U$15, U$32, U$54, U$58, U$83, U$87, U$112, U$116, U$141, U$145, U$170, U$174, U$199, U$203, U$228, U$232, U$257, U$261: EDGE_20
U$16, U$37, U$66, U$95, U$124, U$153, U$182, U$211, U$240: 372
U$19, U$38, U$67, U$96, U$125, U$154, U$183, U$212, U$241: QWIIC_COPYRIGHT_SMALL
U$20, U$39, U$68, U$97, U$126, U$155, U$184, U$213, U$242: CAMERA3
U$21, U$25, U$40, U$42, U$69, U$71, U$98, U$100, U$127, U$129, U$156, U$158, U$185, U$187, U$214, U$216, U$243, U$245: POWEREDBY_TF#JPG
U$23, U$55, U$84, U$113, U$142, U$171, U$200, U$229, U$258: 171
U$26, U$56, U$85, U$114, U$143, U$172, U$201, U$230, U$259: 182
U$27, U$33, U$63, U$92, U$121, U$150, U$179, U$208, U$237: RST15
U$28, U$35, U$65, U$94, U$123, U$152, U$181, U$210, U$239: GRN1
U$29, U$43, U$72, U$101, U$130, U$159, U$188, U$217, U$246: SFE_LOGO_NAME_.1
U$30, U$44, U$73, U$102, U$131, U$160, U$189, U$218, U$247: OSHW-LOGO-S
U$31, U$57, U$86, U$115, U$144, U$173, U$202, U$231, U$260: 193
Y1, Y2, Y3, Y4, Y5, Y6, Y7, Y8, Y9: 32.768kHz; CRYSTAL-SMD-3.2X1.5MM

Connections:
1.8V: C23.1, J7.10, TP7.P$1, U3.5
1.8V1: C14.1, J12.10, TP14.P$1, U4.5
1.8V2: C34.1, J18.10, TP21.P$1, U8.5
1.8V3: C48.1, J24.10, TP28.P$1, U11.5
1.8V4: C62.1, J30.10, TP35.P$1, U14.5
1.8V5: C76.1, J36.10, TP42.P$1, U17.5
1.8V6: C90.1, J42.10, TP49.P$1, U20.5
1.8V7: C104.1, J48.10, TP56.P$1, U23.5
1.8V8: C118.1, J54.10, TP63.P$1, U26.5
!DTR: C6.1, C7.1, J2.1, R29.2
!DTR1: C15.1, C16.1, J6.1, R23.2
!DTR2: C35.1, C36.1, J13.1, R42.2
!DTR3: C49.1, C50.1, J19.1, R56.2
!DTR4: C63.1, C64.1, J25.1, R70.2
!DTR5: C77.1, C78.1, J31.1, R84.2
!DTR6: C91.1, C92.1, J37.1, R98.2
!DTR7: C105.1, C106.1, J43.1, R112.2
!DTR8: C119.1, C120.1, J49.1, R126.2
A1: J8.2, U6.AD16
A2: J14.2, U9.AD16
A3: J20.2, U12.AD16
A4: J26.2, U15.AD16
A5: J32.2, U18.AD16
A6: J38.2, U21.AD16
A7: J44.2, U24.AD16
A8: J50.2, U27.AD16
A16: J3.2, U5.AD16
ACCEL_I2C_SCL: R12.1, U2.1, U5.~D42
ACCEL_I2C_SCL1: R3.1, U1.1, U6.~D42
ACCEL_I2C_SCL2: R31.1, U7.1, U9.~D42
ACCEL_I2C_SCL3: R45.1, U10.1, U12.~D42
ACCEL_I2C_SCL4: R59.1, U13.1, U15.~D42
ACCEL_I2C_SCL5: R73.1, U16.1, U18.~D42
ACCEL_I2C_SCL6: R87.1, U19.1, U21.~D42
ACCEL_I2C_SCL7: R101.1, U22.1, U24.~D42
ACCEL_I2C_SCL8: R115.1, U25.1, U27.~D42
ACCEL_I2C_SDA: R14.1, U2.4, U5.~D43
ACCEL_I2C_SDA1: R4.1, U1.4, U6.~D43
ACCEL_I2C_SDA2: R32.1, U7.4, U9.~D43
ACCEL_I2C_SDA3: R46.1, U10.4, U12.~D43
ACCEL_I2C_SDA4: R60.1, U13.4, U15.~D43
ACCEL_I2C_SDA5: R74.1, U16.4, U18.~D43
ACCEL_I2C_SDA6: R88.1, U19.4, U21.~D43
ACCEL_I2C_SDA7: R102.1, U22.4, U24.~D43
ACCEL_I2C_SDA8: R116.1, U25.4, U27.~D43
ACCEL_INT1: R26.2, U2.12
ACCEL_INT2: R25.2, U2.11
ACCEL_INT3: R20.2, U1.12
ACCEL_INT4: R19.2, U1.11
ACCEL_INT5: R39.2, U7.12
ACCEL_INT6: R38.2, U7.11
ACCEL_INT7: R53.2, U10.12
ACCEL_INT8: R52.2, U10.11
ACCEL_INT9: R67.2, U13.12
ACCEL_INT10: R66.2, U13.11
ACCEL_INT11: R81.2, U16.12
ACCEL_INT12: R80.2, U16.11
ACCEL_INT13: R95.2, U19.12
ACCEL_INT14: R94.2, U19.11
ACCEL_INT15: R109.2, U22.12
ACCEL_INT16: R108.2, U22.11
ACCEL_INT17: R123.2, U25.12
ACCEL_INT18: R122.2, U25.11
AMBIQ_!RST: C6.2, C17.1, J5.10, R27.1, S3.3, S3.4, U5.~RST
AMBIQ_!RST1: C15.2, C19.1, J11.10, R21.1, S1.3, S1.4, U6.~RST
AMBIQ_!RST2: C35.2, C37.1, J17.10, R40.1, S2.3, S2.4, U9.~RST
AMBIQ_!RST3: C49.2, C51.1, J23.10, R54.1, S4.3, S4.4, U12.~RST
AMBIQ_!RST4: C63.2, C65.1, J29.10, R68.1, S5.3, S5.4, U15.~RST
AMBIQ_!RST5: C77.2, C79.1, J35.10, R82.1, S6.3, S6.4, U18.~RST
AMBIQ_!RST6: C91.2, C93.1, J41.10, R96.1, S7.3, S7.4, U21.~RST
AMBIQ_!RST7: C105.2, C107.1, J47.10, R110.1, S8.3, S8.4, U24.~RST
AMBIQ_!RST8: C119.2, C121.1, J53.10, R124.1, S9.3, S9.4, U27.~RST
BOOT: C7.2, R28.2, U5.BOOT
BOOT1: C16.2, R22.2, U6.BOOT
BOOT2: C36.2, R41.2, U9.BOOT
BOOT3: C50.2, R55.2, U12.BOOT
BOOT4: C64.2, R69.2, U15.BOOT
BOOT5: C78.2, R83.2, U18.BOOT
BOOT6: C92.2, R97.2, U21.BOOT
BOOT7: C106.2, R111.2, U24.BOOT
BOOT8: C120.2, R125.2, U27.BOOT
CAMERA_D0: J7.14, U5.D14
CAMERA_D1: J7.3, U5.~AD11
CAMERA_D2: J7.9, U5.~D25
CAMERA_D3: J7.5, U5.AD34
CAMERA_D4: J7.12, U5.~D6
CAMERA_D5: J7.20, U5.~D5
CAMERA_D6: J7.19, U5.~AD35
CAMERA_D7: J7.13, U5.~D28
CAMERA_D8: J12.5, U6.AD34
CAMERA_D9: J12.3, U6.~AD11
CAMERA_D10: J12.9, U6.~D25
CAMERA_D11: J12.12, U6.~D6
CAMERA_D12: J12.14, U6.D14
CAMERA_D13: J12.13, U6.~D28
CAMERA_D14: J12.19, U6.~AD35
CAMERA_D15: J12.20, U6.~D5
CAMERA_D16: J18.5, U9.AD34
CAMERA_D17: J18.3, U9.~AD11
CAMERA_D18: J18.9, U9.~D25
CAMERA_D19: J18.12, U9.~D6
CAMERA_D20: J18.14, U9.D14
CAMERA_D21: J18.13, U9.~D28
CAMERA_D22: J18.19, U9.~AD35
CAMERA_D23: J18.20, U9.~D5
CAMERA_D24: J24.5, U12.AD34
CAMERA_D25: J24.3, U12.~AD11
CAMERA_D26: J24.9, U12.~D25
CAMERA_D27: J24.12, U12.~D6
CAMERA_D28: J24.14, U12.D14
CAMERA_D29: J24.13, U12.~D28
CAMERA_D30: J24.19, U12.~AD35
CAMERA_D31: J24.20, U12.~D5
CAMERA_D32: J30.5, U15.AD34
CAMERA_D33: J30.3, U15.~AD11
CAMERA_D34: J30.9, U15.~D25
CAMERA_D35: J30.12, U15.~D6
CAMERA_D36: J30.14, U15.D14
CAMERA_D37: J30.13, U15.~D28
CAMERA_D38: J30.19, U15.~AD35
CAMERA_D39: J30.20, U15.~D5
CAMERA_D40: J36.5, U18.AD34
CAMERA_D41: J36.3, U18.~AD11
CAMERA_D42: J36.9, U18.~D25
CAMERA_D43: J36.12, U18.~D6
CAMERA_D44: J36.14, U18.D14
CAMERA_D45: J36.13, U18.~D28
CAMERA_D46: J36.19, U18.~AD35
CAMERA_D47: J36.20, U18.~D5
CAMERA_D48: J42.5, U21.AD34
CAMERA_D49: J42.3, U21.~AD11
CAMERA_D50: J42.9, U21.~D25
CAMERA_D51: J42.12, U21.~D6
CAMERA_D52: J42.14, U21.D14
CAMERA_D53: J42.13, U21.~D28
CAMERA_D54: J42.19, U21.~AD35
CAMERA_D55: J42.20, U21.~D5
CAMERA_D56: J48.5, U24.AD34
CAMERA_D57: J48.3, U24.~AD11
CAMERA_D58: J48.9, U24.~D25
CAMERA_D59: J48.12, U24.~D6
CAMERA_D60: J48.14, U24.D14
CAMERA_D61: J48.13, U24.~D28
CAMERA_D62: J48.19, U24.~AD35
CAMERA_D63: J48.20, U24.~D5
CAMERA_D64: J54.5, U27.AD34
CAMERA_D65: J54.3, U27.~AD11
CAMERA_D66: J54.9, U27.~D25
CAMERA_D67: J54.12, U27.~D6
CAMERA_D68: J54.14, U27.D14
CAMERA_D69: J54.13, U27.~D28
CAMERA_D70: J54.19, U27.~AD35
CAMERA_D71: J54.20, U27.~D5
CAMERA_DVDD_EN: R11.2, U3.3, U5.~AD32
CAMERA_DVDD_EN1: R18.2, U4.3, U6.~AD32
CAMERA_DVDD_EN2: R37.2, U8.3, U9.~AD32
CAMERA_DVDD_EN3: R51.2, U11.3, U12.~AD32
CAMERA_DVDD_EN4: R65.2, U14.3, U15.~AD32
CAMERA_DVDD_EN5: R79.2, U17.3, U18.~AD32
CAMERA_DVDD_EN6: R93.2, U20.3, U21.~AD32
CAMERA_DVDD_EN7: R107.2, U23.3, U24.~AD32
CAMERA_DVDD_EN8: R121.2, U26.3, U27.~AD32
CAMERA_HSYNC: J7.16, U5.~D27
CAMERA_HSYNC1: J12.16, U6.~D27
CAMERA_HSYNC2: J18.16, U9.~D27
CAMERA_HSYNC3: J24.16, U12.~D27
CAMERA_HSYNC4: J30.16, U15.~D27
CAMERA_HSYNC5: J36.16, U18.~D27
CAMERA_HSYNC6: J42.16, U21.~D27
CAMERA_HSYNC7: J48.16, U24.~D27
CAMERA_HSYNC8: J54.16, U27.~D27
CAMERA_I2C_SCL: J7.21, R13.1, U5.D8
CAMERA_I2C_SCL1: J12.21, R1.1, U6.D8
CAMERA_I2C_SCL2: J18.21, R24.1, U9.D8
CAMERA_I2C_SCL3: J24.21, R43.1, U12.D8
CAMERA_I2C_SCL4: J30.21, R57.1, U15.D8
CAMERA_I2C_SCL5: J36.21, R71.1, U18.D8
CAMERA_I2C_SCL6: J42.21, R85.1, U21.D8
CAMERA_I2C_SCL7: J48.21, R99.1, U24.D8
CAMERA_I2C_SCL8: J54.21, R113.1, U27.D8
CAMERA_I2C_SDA: J7.22, R15.1, U5.D9
CAMERA_I2C_SDA1: J12.22, R2.1, U6.D9
CAMERA_I2C_SDA2: J18.22, R30.1, U9.D9
CAMERA_I2C_SDA3: J24.22, R44.1, U12.D9
CAMERA_I2C_SDA4: J30.22, R58.1, U15.D9
CAMERA_I2C_SDA5: J36.22, R72.1, U18.D9
CAMERA_I2C_SDA6: J42.22, R86.1, U21.D9
CAMERA_I2C_SDA7: J48.22, R100.1, U24.D9
CAMERA_I2C_SDA8: J54.22, R114.1, U27.D9
CAMERA_INT: J7.18, U5.~D23
CAMERA_INT1: J12.18, U6.~D23
CAMERA_INT2: J18.18, U9.~D23
CAMERA_INT3: J24.18, U12.~D23
CAMERA_INT4: J30.18, U15.~D23
CAMERA_INT5: J36.18, U18.~D23
CAMERA_INT6: J42.18, U21.~D23
CAMERA_INT7: J48.18, U24.~D23
CAMERA_INT8: J54.18, U27.~D23
CAMERA_MCLK: J7.8, U5.~D26
CAMERA_MCLK1: J12.8, U6.~D26
CAMERA_MCLK2: J18.8, U9.~D26
CAMERA_MCLK3: J24.8, U12.~D26
CAMERA_MCLK4: J30.8, U15.~D26
CAMERA_MCLK5: J36.8, U18.~D26
CAMERA_MCLK6: J42.8, U21.~D26
CAMERA_MCLK7: J48.8, U24.~D26
CAMERA_MCLK8: J54.8, U27.~D26
CAMERA_PCLK: J7.17, U5.D7
CAMERA_PCLK1: J12.17, U6.D7
CAMERA_PCLK2: J18.17, U9.D7
CAMERA_PCLK3: J24.17, U12.D7
CAMERA_PCLK4: J30.17, U15.D7
CAMERA_PCLK5: J36.17, U18.D7
CAMERA_PCLK6: J42.17, U21.D7
CAMERA_PCLK7: J48.17, U24.D7
CAMERA_PCLK8: J54.17, U27.D7
CAMERA_TRIG: J7.7, U5.~AD13
CAMERA_TRIG1: J12.7, U6.~AD13
CAMERA_TRIG2: J18.7, U9.~AD13
CAMERA_TRIG3: J24.7, U12.~AD13
CAMERA_TRIG4: J30.7, U15.~AD13
CAMERA_TRIG5: J36.7, U18.~AD13
CAMERA_TRIG6: J42.7, U21.~AD13
CAMERA_TRIG7: J48.7, U24.~AD13
CAMERA_TRIG8: J54.7, U27.~AD13
CAMERA_VSYNC: J7.6, U5.D15
CAMERA_VSYNC1: J12.6, U6.D15
CAMERA_VSYNC2: J18.6, U9.D15
CAMERA_VSYNC3: J24.6, U12.D15
CAMERA_VSYNC4: J30.6, U15.D15
CAMERA_VSYNC5: J36.6, U18.D15
CAMERA_VSYNC6: J42.6, U21.D15
CAMERA_VSYNC7: J48.6, U24.D15
CAMERA_VSYNC8: J54.6, U27.D15
FTDI_VCC: D2.A, J2.4
FTDI_VCC1: D8.A, J6.4
FTDI_VCC2: D14.A, J13.4
FTDI_VCC3: D20.A, J19.4
FTDI_VCC4: D26.A, J25.4
FTDI_VCC5: D32.A, J31.4
FTDI_VCC6: D38.A, J37.4
FTDI_VCC7: D44.A, J43.4
FTDI_VCC8: D50.A, J49.4
GND: BT1.2, C1.2, C2.1, C4.2, C9.1, C10.1, C11.2, C17.2, C18.2, C20.2, C21.2, C22.2, C23.2, D3.C, D4.C, D5.C, D6.C, E1.2, E1.3, E1.6, E1.7, E1.8, E2.3, E2.6, E2.7, E2.8, J1.1, J1.2, J1.3, J1.4, J1.5, J2.6, J4.1, J5.3, J5.5, J5.9, J7.2, J7.15, R11.1, R28.1, R29.1, S3.1, S3.2, U2.5, U2.6, U2.7, U2.8, U3.2, U5.GND@1, U5.GND@22, U5.GND@38, U5.GND@39, U5.GND@47, U5.GND@59
GND1: BT2.2, C3.1, C5.1, C8.2, C12.2, C13.2, C14.2, C19.2, C24.2, C25.1, C26.2, C27.2, C28.2, D9.C, D10.C, D11.C, D12.C, E3.2, E3.3, E3.6, E3.7, E3.8, E4.3, E4.6, E4.7, E4.8, J6.6, J9.1, J9.2, J9.3, J9.4, J9.5, J10.1, J11.3, J11.5, J11.9, J12.2, J12.15, R18.1, R22.1, R23.1, S1.1, S1.2, U1.5, U1.6, U1.7, U1.8, U4.2, U6.GND@1, U6.GND@22, U6.GND@38, U6.GND@39, U6.GND@47, U6.GND@59
GND2: BT3.2, C29.1, C30.1, C31.2, C32.2, C33.2, C34.2, C37.2, C38.2, C39.1, C40.2, C41.2, C42.2, D15.C, D16.C, D17.C, D18.C, E5.2, E5.3, E5.6, E5.7, E5.8, E6.3, E6.6, E6.7, E6.8, J13.6, J15.1, J15.2, J15.3, J15.4, J15.5, J16.1, J17.3, J17.5, J17.9, J18.2, J18.15, R37.1, R41.1, R42.1, S2.1, S2.2, U7.5, U7.6, U7.7, U7.8, U8.2, U9.GND@1, U9.GND@22, U9.GND@38, U9.GND@39, U9.GND@47, U9.GND@59
GND3: BT4.2, C43.1, C44.1, C45.2, C46.2, C47.2, C48.2, C51.2, C52.2, C53.1, C54.2, C55.2, C56.2, D21.C, D22.C, D23.C, D24.C, E7.2, E7.3, E7.6, E7.7, E7.8, E8.3, E8.6, E8.7, E8.8, J19.6, J21.1, J21.2, J21.3, J21.4, J21.5, J22.1, J23.3, J23.5, J23.9, J24.2, J24.15, R51.1, R55.1, R56.1, S4.1, S4.2, U10.5, U10.6, U10.7, U10.8, U11.2, U12.GND@1, U12.GND@22, U12.GND@38, U12.GND@39, U12.GND@47, U12.GND@59
GND4: BT5.2, C57.1, C58.1, C59.2, C60.2, C61.2, C62.2, C65.2, C66.2, C67.1, C68.2, C69.2, C70.2, D27.C, D28.C, D29.C, D30.C, E9.2, E9.3, E9.6, E9.7, E9.8, E10.3, E10.6, E10.7, E10.8, J25.6, J27.1, J27.2, J27.3, J27.4, J27.5, J28.1, J29.3, J29.5, J29.9, J30.2, J30.15, R65.1, R69.1, R70.1, S5.1, S5.2, U13.5, U13.6, U13.7, U13.8, U14.2, U15.GND@1, U15.GND@22, U15.GND@38, U15.GND@39, U15.GND@47, U15.GND@59
GND5: BT6.2, C71.1, C72.1, C73.2, C74.2, C75.2, C76.2, C79.2, C80.2, C81.1, C82.2, C83.2, C84.2, D33.C, D34.C, D35.C, D36.C, E11.2, E11.3, E11.6, E11.7, E11.8, E12.3, E12.6, E12.7, E12.8, J31.6, J33.1, J33.2, J33.3, J33.4, J33.5, J34.1, J35.3, J35.5, J35.9, J36.2, J36.15, R79.1, R83.1, R84.1, S6.1, S6.2, U16.5, U16.6, U16.7, U16.8, U17.2, U18.GND@1, U18.GND@22, U18.GND@38, U18.GND@39, U18.GND@47, U18.GND@59
GND6: BT7.2, C85.1, C86.1, C87.2, C88.2, C89.2, C90.2, C93.2, C94.2, C95.1, C96.2, C97.2, C98.2, D39.C, D40.C, D41.C, D42.C, E13.2, E13.3, E13.6, E13.7, E13.8, E14.3, E14.6, E14.7, E14.8, J37.6, J39.1, J39.2, J39.3, J39.4, J39.5, J40.1, J41.3, J41.5, J41.9, J42.2, J42.15, R93.1, R97.1, R98.1, S7.1, S7.2, U19.5, U19.6, U19.7, U19.8, U20.2, U21.GND@1, U21.GND@22, U21.GND@38, U21.GND@39, U21.GND@47, U21.GND@59
GND7: BT8.2, C99.1, C100.1, C101.2, C102.2, C103.2, C104.2, C107.2, C108.2, C109.1, C110.2, C111.2, C112.2, D45.C, D46.C, D47.C, D48.C, E15.2, E15.3, E15.6, E15.7, E15.8, E16.3, E16.6, E16.7, E16.8, J43.6, J45.1, J45.2, J45.3, J45.4, J45.5, J46.1, J47.3, J47.5, J47.9, J48.2, J48.15, R107.1, R111.1, R112.1, S8.1, S8.2, U22.5, U22.6, U22.7, U22.8, U23.2, U24.GND@1, U24.GND@22, U24.GND@38, U24.GND@39, U24.GND@47, U24.GND@59
GND8: BT9.2, C113.1, C114.1, C115.2, C116.2, C117.2, C118.2, C121.2, C122.2, C123.1, C124.2, C125.2, C126.2, D51.C, D52.C, D53.C, D54.C, E17.2, E17.3, E17.6, E17.7, E17.8, E18.3, E18.6, E18.7, E18.8, J49.6, J51.1, J51.2, J51.3, J51.4, J51.5, J52.1, J53.3, J53.5, J53.9, J54.2, J54.15, R121.1, R125.1, R126.1, S9.1, S9.2, U25.5, U25.6, U25.7, U25.8, U26.2, U27.GND@1, U27.GND@22, U27.GND@38, U27.GND@39, U27.GND@47, U27.GND@59
LED_BLUE: R6.2, U5.~D18
LED_BLUE1: R9.2, U6.~D18
LED_BLUE2: R33.2, U9.~D18
LED_BLUE3: R47.2, U12.~D18
LED_BLUE4: R61.2, U15.~D18
LED_BLUE5: R75.2, U18.~D18
LED_BLUE6: R89.2, U21.~D18
LED_BLUE7: R103.2, U24.~D18
LED_BLUE8: R117.2, U27.~D18
LED_GREEN: R8.2, U5.D17
LED_GREEN1: R17.2, U6.D17
LED_GREEN2: R36.2, U9.D17
LED_GREEN3: R50.2, U12.D17
LED_GREEN4: R64.2, U15.D17
LED_GREEN5: R78.2, U18.D17
LED_GREEN6: R92.2, U21.D17
LED_GREEN7: R106.2, U24.D17
LED_GREEN8: R120.2, U27.D17
LED_RED: R5.2, U5.~D19
LED_RED1: R10.2, U6.~D19
LED_RED2: R34.2, U9.~D19
LED_RED3: R48.2, U12.~D19
LED_RED4: R62.2, U15.~D19
LED_RED5: R76.2, U18.~D19
LED_RED6: R90.2, U21.~D19
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

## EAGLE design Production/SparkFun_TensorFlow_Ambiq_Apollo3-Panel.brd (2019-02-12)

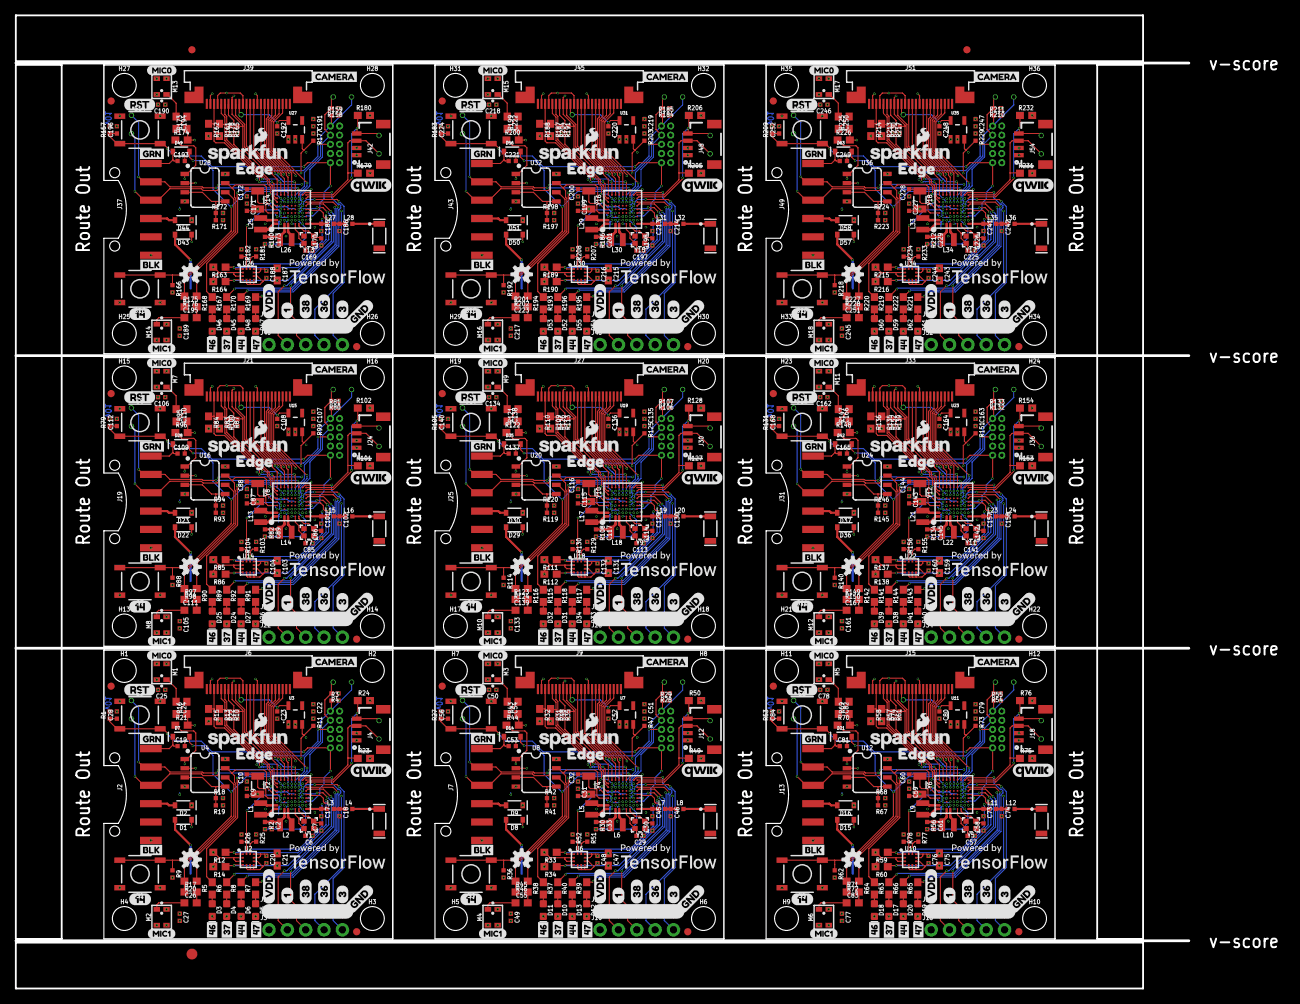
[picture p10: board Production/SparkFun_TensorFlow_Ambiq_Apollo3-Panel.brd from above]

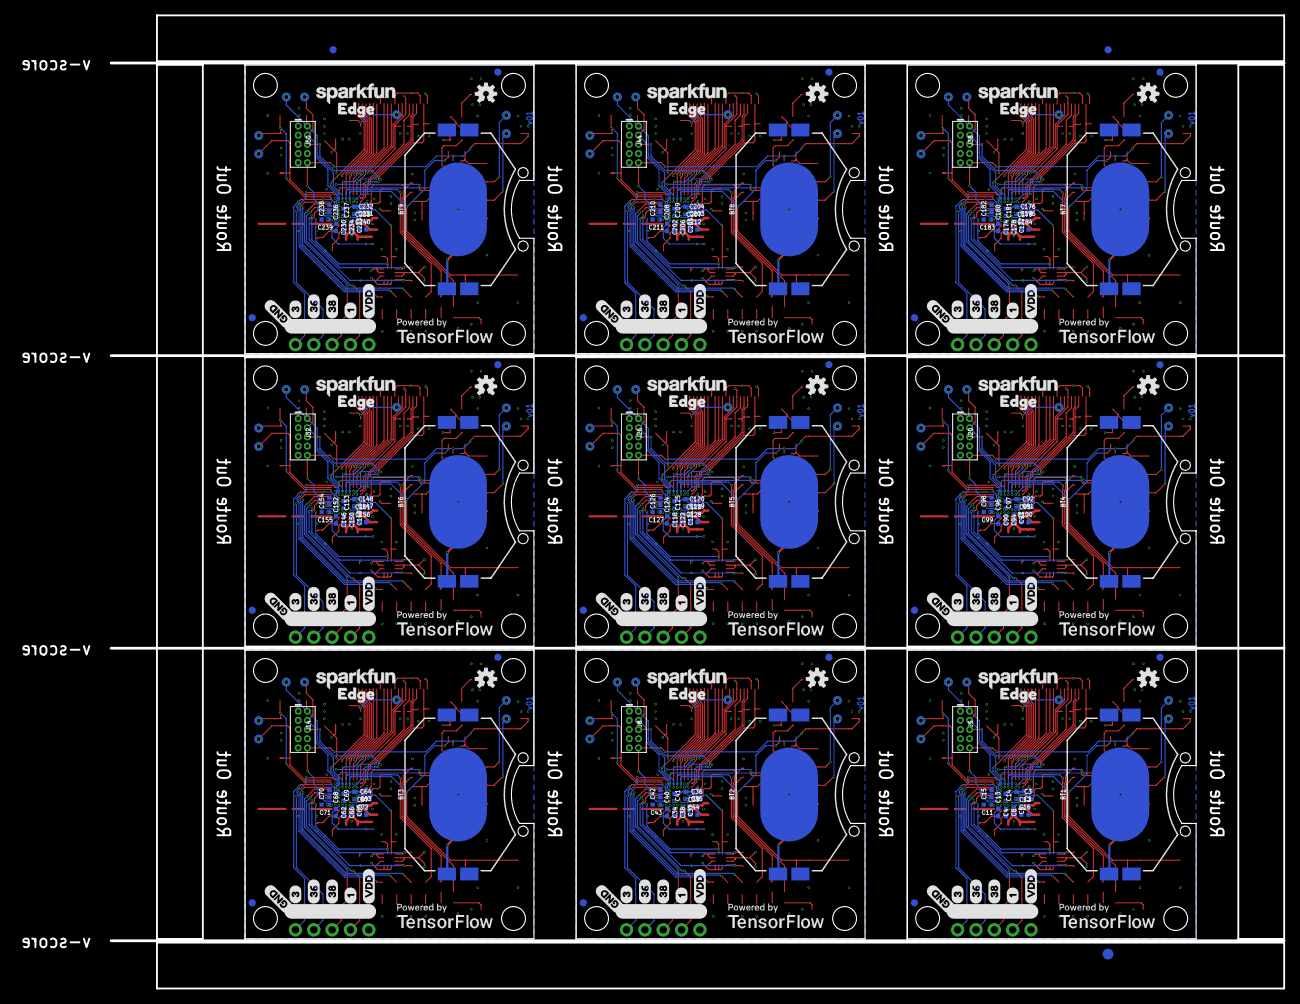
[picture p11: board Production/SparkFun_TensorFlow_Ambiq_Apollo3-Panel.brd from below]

Board: 4 copper layers, 162.4 x 134.7 mm, 1176 parts (291 on the bottom side), 666 nets.

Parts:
A1, A2, A3, A4, A5, A6, A7, A8, A9: 2.4GHZ-3.2X1.6MM; ANT-2.4GHZ-3.2X1.6X1.2MM
BT1, BT2, BT3, BT4, BT5, BT6, BT7, BT8, BT9: BATTCON_20MM_4LEGS_OVERPASTE_INNER
C1, C35, C63, C91, C119, C147, C175, C203, C231: 0.47uF; 0402-TIGHT
C2, C33, C61, C89, C117, C145, C173, C201, C229: 4.7uF; 0402-TIGHT
C3, C5, C8, C16, C36, C37, C38, C44, C64, C65, C66, C72, C92, C93, C94, C100, C120, C121, C122, C128, C148, C149, C150, C156, C176, C177, C178, C184, C204, C205, C206, C212, C232, C233, C234, C240: 2.2uF; 0402-TIGHT
C4, C12, C13, C14, C15, C22, C23, C34, C39, C40, C41, C42, C51, C52, C62, C67, C68, C69, C70, C79, C80, C90, C95, C96, C97, C98, C107, C108, C118, C123, C124, C125, C126, C135, C136, C146, C151, C152, C153, C154, C163, C164, C174, C179, C180, C181, C182, C191, C192, C202, C207, C208, C209, C210, C219, C220, C230, C235, C236, C237, C238, C247, C248: 1.0uF; 0402-TIGHT
C6, C7, C29, C30, C57, C58, C85, C86, C113, C114, C141, C142, C169, C170, C197, C198, C225, C226: 6pF; 0402-TIGHT
C9, C10, C31, C32, C59, C60, C87, C88, C115, C116, C143, C144, C171, C172, C199, C200, C227, C228: 15pF; 0402-TIGHT
C11, C43, C71, C99, C127, C155, C183, C211, C239: 47nF; 0402-TIGHT
C17, C45, C73, C101, C129, C157, C185, C213, C241: DNP; 0402-TIGHT
C18, C46, C74, C102, C130, C158, C186, C214, C242: 0.5pF; 0402-TIGHT
C19, C20, C25, C27, C48, C49, C50, C53, C76, C77, C78, C81, C104, C105, C106, C109, C132, C133, C134, C137, C160, C161, C162, C165, C188, C189, C190, C193, C216, C217, C218, C221, C244, C245, C246, C249: 0.1uF; 0402-TIGHT
C21, C47, C75, C103, C131, C159, C187, C215, C243: 10uF; 0603
C24, C26, C54, C55, C82, C83, C110, C111, C138, C139, C166, C167, C194, C195, C222, C223, C250, C251: 4.7uF; 0603
C28, C56, C84, C112, C140, C168, C196, C224, C252: 1.0nF; 0402-TIGHT
D1, D2, D8, D9, D15, D16, D22, D23, D29, D30, D36, D37, D43, D44, D50, D51, D57, D58: 1A/23V/620mV; SOD-323@1
D3, D11, D18, D25, D32, D39, D46, D53, D60: RED; LED-0603
D4, D10, D17, D24, D31, D38, D45, D52, D59: BLUE; LED-0603
D5, D12, D19, D26, D33, D40, D47, D54, D61: Yellow; LED-0603
D6, D13, D20, D27, D34, D41, D48, D55, D62: GREEN; LED-0603
D7, D14, D21, D28, D35, D42, D49, D56, D63: 250mA/100V; SOD-323
E$1, E$2, E$3, E$4: FIDUCIAL-1X2
E$5, E$6: FIDUCIAL-1.5X3
FD1, FD2, FD3, FD4, FD5, FD6, FD7, FD8, FD9, FD10, FD11, FD12, FD13, FD14, FD15, FD16, FD17, FD18, FD19, FD20, FD21, FD22, FD23, FD24, FD25, FD26, FD27, FD28, FD29, FD30, FD31, FD32, FD33, FD34, FD35, FD36: FIDUCIAL1X2; FIDUCIAL-1X2
H1, H2, H3, H4, H5, H6, H7, H8, H9, H10, H11, H12, H13, H14, H15, H16, H17, H18, H19, H20, H21, H22, H23, H24, H25, H26, H27, H28, H29, H30, H31, H32, H33, H34, H35, H36: STAND-OFF
J1, J3, J10, J11, J16, J17, J22, J23, J28, J29, J34, J35, J40, J41, J46, J47, J52, J53: 1X05_NO_SILK
J2, J7, J13, J19, J25, J31, J37, J43, J49: 1X06-SMD_RA_MALE
J4, J12, J18, J24, J30, J36, J42, J48, J54: 1X04_1MM_RA
J5, J8, J14, J20, J26, J32, J38, J44, J50: CORTEX_DEBUG_PTH; 2X5-PTH-1.27MM
J6, J9, J15, J21, J27, J33, J39, J45, J51: CAMERA-0V7670; FPC-24-AMPHENOL-SFV24R-1STE1HLF
L1, L5, L9, L13, L17, L21, L25, L29, L33: 2.2uH; 0805-WIDE
L2, L6, L10, L14, L18, L22, L26, L30, L34: 1.0uH; 0805-WIDE
L3, L7, L11, L15, L19, L23, L27, L31, L35: 2.7nH; 0402-TIGHT
L4, L8, L12, L16, L20, L24, L28, L32, L36: 2.0nH; 0402-TIGHT
LOGO1, LOGO3, LOGO5, LOGO7, LOGO9, LOGO11, LOGO13, LOGO15, LOGO17: SFE_LOGO_NAME_FLAME.1_INCH; SFE_LOGO_NAME_FLAME_.1
LOGO2, LOGO4, LOGO6, LOGO8, LOGO10, LOGO12, LOGO14, LOGO16, LOGO18: OSHW-LOGOS; OSHW-LOGO-S
M1, M2, M3, M4, M5, M6, M7, M8, M9, M10, M11, M12, M13, M14, M15, M16, M17, M18: MEMS_MIC; SPW2430HR5H-B
R1, R3, R4, R9, R10, R11, R19, R22, R25, R26, R27, R28, R29, R35, R36, R41, R47, R48, R51, R52, R53, R54, R55, R61, R62, R67, R73, R74, R77, R78, R79, R80, R81, R87, R88, R93, R99, R100, R103, R104, R105, R106, R107, R113, R114, R119, R125, R126, R129, R130, R131, R132, R133, R139, R140, R145, R151, R152, R155, R156, R157, R158, R159, R165, R166, R171, R177, R178, R181, R182, R183, R184, R185, R191, R192, R197, R203, R204, R207, R208, R209, R210, R211, R217, R218, R223, R229, R230, R233, R234: 10k; 0402-TIGHT
R2, R30, R56, R82, R108, R134, R160, R186, R212: 0; 0402-TIGHT
R5, R6, R7, R8, R37, R38, R39, R40, R63, R64, R65, R66, R89, R90, R91, R92, R115, R116, R117, R118, R141, R142, R143, R144, R167, R168, R169, R170, R193, R194, R195, R196, R219, R220, R221, R222: 1k; 0603
R12, R13, R14, R15, R23, R24, R31, R32, R33, R34, R49, R50, R57, R58, R59, R60, R75, R76, R83, R84, R85, R86, R101, R102, R109, R110, R111, R112, R127, R128, R135, R136, R137, R138, R153, R154, R161, R162, R163, R164, R179, R180, R187, R188, R189, R190, R205, R206, R213, R214, R215, R216, R231, R232: 4.7k; 0603
R16, R17, R43, R45, R69, R71, R95, R97, R121, R123, R147, R149, R173, R175, R199, R201, R225, R227: 10k; 0603
R18, R42, R68, R94, R120, R146, R172, R198, R224: 22k; 0402-TIGHT
R20, R21, R44, R46, R70, R72, R96, R98, R122, R124, R148, R150, R174, R176, R200, R202, R226, R228: 100k; 0603
S1, S2, S3, S4, S5, S6, S7, S8, S9, S10, S11, S12, S13, S14, S15, S16, S17, S18: TACTILE_SWITCH_SMD_5.2MM
TP1, TP2, TP3, TP4, TP5, TP6, TP7, TP8, TP9, TP10, TP11, TP12, TP13, TP14, TP15, TP16, TP17, TP18, TP19, TP20, TP21, TP22, TP23, TP24, TP25, TP26, TP27, TP28, TP29, TP30, TP31, TP32, TP33, TP34, TP35, TP36, TP37, TP38, TP39, TP40, TP41, TP42, TP43, TP44, TP45, TP46, TP47, TP48, TP49, TP50, TP51, TP52, TP53, TP54, TP55, TP56, TP57, TP58, TP59, TP60, TP61, TP62, TP63: TEST-POINT3X5; PAD.03X.05
U1, U5, U9, U13, U17, U21, U25, U29, U33: AMBIQ-APOLLO3KBR; BGA-81-5X5MM
U2, U6, U10, U14, U18, U22, U26, U30, U34: LIS2DH12; LGA-12-LISDH12
U3, U7, U11, U15, U19, U23, U27, U31, U35: 1.8V; SOT23-5
U4, U8, U12, U16, U20, U24, U28, U32, U36: LMV358; SO08
U$1, U$55, U$85, U$115, U$145, U$175, U$205, U$235, U$265: MIC00
U$2, U$41, U$71, U$101, U$131, U$161, U$191, U$221, U$251: BLK2
U$3, U$14, U$31, U$38, U$61, U$68, U$91, U$98, U$121, U$128, U$151, U$158, U$181, U$188, U$211, U$218, U$241, U$248: GND0
U$4, U$9, U$32, U$35, U$62, U$65, U$92, U$95, U$122, U$125, U$152, U$155, U$182, U$185, U$212, U$215, U$242, U$245: VDD1
U$5, U$8, U$43, U$44, U$73, U$74, U$103, U$104, U$133, U$134, U$163, U$164, U$193, U$194, U$223, U$224, U$253, U$254: 10
U$6, U$11, U$33, U$36, U$63, U$66, U$93, U$96, U$123, U$126, U$153, U$156, U$183, U$186, U$213, U$216, U$243, U$246: 383
U$7, U$12, U$34, U$37, U$64, U$67, U$94, U$97, U$124, U$127, U$154, U$157, U$184, U$187, U$214, U$217, U$244, U$247: 364
U$10, U$13, U$45, U$46, U$75, U$76, U$105, U$106, U$135, U$136, U$165, U$166, U$195, U$196, U$225, U$226, U$255, U$256: 31
U$15, U$47, U$77, U$107, U$137, U$167, U$197, U$227, U$257: 461
U$16, U$48, U$78, U$108, U$138, U$168, U$198, U$228, U$258: 372
U$17, U$49, U$79, U$109, U$139, U$169, U$199, U$229, U$259: 443
U$18, U$50, U$80, U$110, U$140, U$170, U$200, U$230, U$260: 470
U$19, U$51, U$81, U$111, U$141, U$171, U$201, U$231, U$261: QWIIC_COPYRIGHT_SMALL
U$20, U$52, U$82, U$112, U$142, U$172, U$202, U$232, U$262: CAMERA3
U$21, U$25, U$53, U$58, U$83, U$88, U$113, U$118, U$143, U$148, U$173, U$178, U$203, U$208, U$233, U$238, U$263, U$268: POWEREDBY_TF#JPG
U$22, U$56, U$86, U$116, U$146, U$176, U$206, U$236, U$266: MIC11
U$23, U$24, U$54, U$57, U$84, U$87, U$114, U$117, U$144, U$147, U$174, U$177, U$204, U$207, U$234, U$237, U$264, U$267: EDGE0
U$26, U$39, U$69, U$99, U$129, U$159, U$189, U$219, U$249: 1416
U$27, U$40, U$70, U$100, U$130, U$160, U$190, U$220, U$250: RST15
U$28, U$42, U$72, U$102, U$132, U$162, U$192, U$222, U$252: GRN1
U$29, U$59, U$89, U$119, U$149, U$179, U$209, U$239, U$269: SFE_LOGO_NAME_.1
U$30, U$60, U$90, U$120, U$150, U$180, U$210, U$240, U$270: OSHW-LOGO-S
Y1, Y3, Y5, Y7, Y9, Y11, Y13, Y15, Y17: 32MHz; CRYSTAL-SMD-2.0X1.6MM
Y2, Y4, Y6, Y8, Y10, Y12, Y14, Y16, Y18: 32.768kHz; CRYSTAL-SMD-3.2X1.5MM

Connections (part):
1.8V: C23.1, J6.10, TP7.P$1, U3.5
1.8V1: C52.1, J9.10, TP14.P$1, U7.5
1.8V2: C80.1, J15.10, TP21.P$1, U11.5
1.8V3: C108.1, J21.10, TP28.P$1, U15.5
1.8V4: C136.1, J27.10, TP35.P$1, U19.5
1.8V5: C164.1, J33.10, TP42.P$1, U23.5
1.8V6: C192.1, J39.10, TP49.P$1, U27.5
1.8V7: C220.1, J45.10, TP56.P$1, U31.5
1.8V8: C248.1, J51.10, TP63.P$1, U35.5
ADC_VREF: C1.1, U1.A6
ADC_VREF1: C35.1, U5.A6
ADC_VREF2: C63.1, U9.A6
ADC_VREF3: C91.1, U13.A6
ADC_VREF4: C119.1, U17.A6
ADC_VREF5: C147.1, U21.A6
ADC_VREF6: C175.1, U25.A6
ADC_VREF7: C203.1, U29.A6
ADC_VREF8: C231.1, U33.A6
AMBIQ_!RST: C19.2, C28.1, J5.10, R1.1, S2.3, S2.4, U1.G3
AMBIQ_!RST1: C53.2, C56.1, J8.10, R27.1, S4.3, S4.4, U5.G3
AMBIQ_!RST2: C81.2, C84.1, J14.10, R53.1, S6.3, S6.4, U9.G3
AMBIQ_!RST3: C109.2, C112.1, J20.10, R79.1, S8.3, S8.4, U13.G3
AMBIQ_!RST4: C137.2, C140.1, J26.10, R105.1, S10.3, S10.4, U17.G3
AMBIQ_!RST5: C165.2, C168.1, J32.10, R131.1, S12.3, S12.4, U21.G3
AMBIQ_!RST6: C193.2, C196.1, J38.10, R157.1, S14.3, S14.4, U25.G3
AMBIQ_!RST7: C221.2, C224.1, J44.10, R183.1, S16.3, S16.4, U29.G3
AMBIQ_!RST8: C249.2, C252.1, J50.10, R209.1, S18.3, S18.4, U33.G3
DTR: C19.1, D7.C, J2.1
DTR1: C53.1, D14.C, J7.1
DTR2: C81.1, D21.C, J13.1
DTR3: C109.1, D28.C, J19.1
DTR4: C137.1, D35.C, J25.1
DTR5: C165.1, D42.C, J31.1
DTR6: C193.1, D49.C, J37.1
DTR7: C221.1, D56.C, J43.1
DTR8: C249.1, D63.C, J49.1
DVDD: C11.1, U1.H3
DVDD1: C43.1, U5.H3
DVDD2: C71.1, U9.H3
DVDD3: C99.1, U13.H3
DVDD4: C127.1, U17.H3
DVDD5: C155.1, U21.H3
DVDD6: C183.1, U25.H3
DVDD7: C211.1, U29.H3
DVDD8: C239.1, U33.H3
FTDI_VCC: D2.A, J2.4
FTDI_VCC1: D9.A, J7.4
FTDI_VCC2: D16.A, J13.4
FTDI_VCC3: D23.A, J19.4
FTDI_VCC4: D30.A, J25.4
FTDI_VCC5: D37.A, J31.4
FTDI_VCC6: D44.A, J37.4
FTDI_VCC7: D51.A, J43.4
FTDI_VCC8: D58.A, J49.4
GND: BT1.2, C1.2, C2.2, C3.2, C4.2, C5.2, C6.1, C7.1, C8.2, C9.1, C10.1, C11.2, C12.2, C13.2, C14.2, C15.2, C16.2, C17.2, C18.2, C20.2, C21.2, C22.2, C23.2, C25.2, C27.2, C28.2, D3.C, D4.C, D5.C, D6.C, J1.1, J1.2, J1.3, J1.4, J1.5, J2.6, J4.1, J5.3, J5.5, J5.9, J6.2, J6.15, M1.2, M1.3, M2.2, M2.3, R4.1, R11.1, R19.1, R22.1, S1.1, S1.2, S2.1, S2.2, U1.B3, U1.C2, U1.E2, U1.E3, U1.F2, U1.H1, U1.H2, U1.J2, U2.5, U2.6, U2.7, U2.8, U3.2, U4.4
GND1: BT2.2, C29.1, C30.1, C31.1, C32.1, C33.2, C34.2, C35.2, C36.2, C37.2, C38.2, C39.2, C40.2, C41.2, C42.2, C43.2, C44.2, C45.2, C46.2, C47.2, C48.2, C49.2, C50.2, C51.2, C52.2, C56.2, D10.C, D11.C, D12.C, D13.C, J7.6, J8.3, J8.5, J8.9, J9.2, J9.15, J11.1, J11.2, J11.3, J11.4, J11.5, J12.1, M3.2, M3.3, M4.2, M4.3, R28.1, R41.1, R47.1, R48.1, S3.1, S3.2, S4.1, S4.2, U5.B3, U5.C2, U5.E2, U5.E3, U5.F2, U5.H1, U5.H2, U5.J2, U6.5, U6.6, U6.7, U6.8, U7.2, U8.4
GND2: BT3.2, C57.1, C58.1, C59.1, C60.1, C61.2, C62.2, C63.2, C64.2, C65.2, C66.2, C67.2, C68.2, C69.2, C70.2, C71.2, C72.2, C73.2, C74.2, C75.2, C76.2, C77.2, C78.2, C79.2, C80.2, C84.2, D17.C, D18.C, D19.C, D20.C, J13.6, J14.3, J14.5, J14.9, J15.2, J15.15, J17.1, J17.2, J17.3, J17.4, J17.5, J18.1, M5.2, M5.3, M6.2, M6.3, R54.1, R67.1, R73.1, R74.1, S5.1, S5.2, S6.1, S6.2, U9.B3, U9.C2, U9.E2, U9.E3, U9.F2, U9.H1, U9.H2, U9.J2, U10.5, U10.6, U10.7, U10.8, U11.2, U12.4
GND3: BT4.2, C85.1, C86.1, C87.1, C88.1, C89.2, C90.2, C91.2, C92.2, C93.2, C94.2, C95.2, C96.2, C97.2, C98.2, C99.2, C100.2, C101.2, C102.2, C103.2, C104.2, C105.2, C106.2, C107.2, C108.2, C112.2, D24.C, D25.C, D26.C, D27.C, J19.6, J20.3, J20.5, J20.9, J21.2, J21.15, J23.1, J23.2, J23.3, J23.4, J23.5, J24.1, M7.2, M7.3, M8.2, M8.3, R80.1, R93.1, R99.1, R100.1, S7.1, S7.2, S8.1, S8.2, U13.B3, U13.C2, U13.E2, U13.E3, U13.F2, U13.H1, U13.H2, U13.J2, U14.5, U14.6, U14.7, U14.8, U15.2, U16.4
GND4: BT5.2, C113.1, C114.1, C115.1, C116.1, C117.2, C118.2, C119.2, C120.2, C121.2, C122.2, C123.2, C124.2, C125.2, C126.2, C127.2, C128.2, C129.2, C130.2, C131.2, C132.2, C133.2, C134.2, C135.2, C136.2, C140.2, D31.C, D32.C, D33.C, D34.C, J25.6, J26.3, J26.5, J26.9, J27.2, J27.15, J29.1, J29.2, J29.3, J29.4, J29.5, J30.1, M9.2, M9.3, M10.2, M10.3, R106.1, R119.1, R125.1, R126.1, S9.1, S9.2, S10.1, S10.2, U17.B3, U17.C2, U17.E2, U17.E3, U17.F2, U17.H1, U17.H2, U17.J2, U18.5, U18.6, U18.7, U18.8, U19.2, U20.4
GND5: BT6.2, C141.1, C142.1, C143.1, C144.1, C145.2, C146.2, C147.2, C148.2, C149.2, C150.2, C151.2, C152.2, C153.2, C154.2, C155.2, C156.2, C157.2, C158.2, C159.2, C160.2, C161.2, C162.2, C163.2, C164.2, C168.2, D38.C, D39.C, D40.C, D41.C, J31.6, J32.3, J32.5, J32.9, J33.2, J33.15, J35.1, J35.2, J35.3, J35.4, J35.5, J36.1, M11.2, M11.3, M12.2, M12.3, R132.1, R145.1, R151.1, R152.1, S11.1, S11.2, S12.1, S12.2, U21.B3, U21.C2, U21.E2, U21.E3, U21.F2, U21.H1, U21.H2, U21.J2, U22.5, U22.6, U22.7, U22.8, U23.2, U24.4
GND6: BT7.2, C169.1, C170.1, C171.1, C172.1, C173.2, C174.2, C175.2, C176.2, C177.2, C178.2, C179.2, C180.2, C181.2, C182.2, C183.2, C184.2, C185.2, C186.2, C187.2, C188.2, C189.2, C190.2, C191.2, C192.2, C196.2, D45.C, D46.C, D47.C, D48.C, J37.6, J38.3, J38.5, J38.9, J39.2, J39.15, J41.1, J41.2, J41.3, J41.4, J41.5, J42.1, M13.2, M13.3, M14.2, M14.3, R158.1, R171.1, R177.1, R178.1, S13.1, S13.2, S14.1, S14.2, U25.B3, U25.C2, U25.E2, U25.E3, U25.F2, U25.H1, U25.H2, U25.J2, U26.5, U26.6, U26.7, U26.8, U27.2, U28.4
GND7: BT8.2, C197.1, C198.1, C199.1, C200.1, C201.2, C202.2, C203.2, C204.2, C205.2, C206.2, C207.2, C208.2, C209.2, C210.2, C211.2, C212.2, C213.2, C214.2, C215.2, C216.2, C217.2, C218.2, C219.2, C220.2, C224.2, D52.C, D53.C, D54.C, D55.C, J43.6, J44.3, J44.5, J44.9, J45.2, J45.15, J47.1, J47.2, J47.3, J47.4, J47.5, J48.1, M15.2, M15.3, M16.2, M16.3, R184.1, R197.1, R203.1, R204.1, S15.1, S15.2, S16.1, S16.2, U29.B3, U29.C2, U29.E2, U29.E3, U29.F2, U29.H1, U29.H2, U29.J2, U30.5, U30.6, U30.7, U30.8, U31.2, U32.4
GND8: BT9.2, C225.1, C226.1, C227.1, C228.1, C229.2, C230.2, C231.2, C232.2, C233.2, C234.2, C235.2, C236.2, C237.2, C238.2, C239.2, C240.2, C241.2, C242.2, C243.2, C244.2, C245.2, C246.2, C247.2, C248.2, C252.2, D59.C, D60.C, D61.C, D62.C, J49.6, J50.3, J50.5, J50.9, J51.2, J51.15, J53.1, J53.2, J53.3, J53.4, J53.5, J54.1, M17.2, M17.3, M18.2, M18.3, R210.1, R223.1, R229.1, R230.1, S17.1, S17.2, S18.1, S18.2, U33.B3, U33.C2, U33.E2, U33.E3, U33.F2, U33.H1, U33.H2, U33.J2, U34.5, U34.6, U34.7, U34.8, U35.2, U36.4
GPIO0/ACCEL_INT1: R51.2, U5.H4, U6.11
GPIO0/ACCEL_INT2: R25.2, U1.H4, U2.11
GPIO0/ACCEL_INT3: R77.2, U9.H4, U10.11
GPIO0/ACCEL_INT4: R103.2, U13.H4, U14.11
GPIO0/ACCEL_INT5: R129.2, U17.H4, U18.11
GPIO0/ACCEL_INT6: R155.2, U21.H4, U22.11
GPIO0/ACCEL_INT7: R181.2, U25.H4, U26.11
GPIO0/ACCEL_INT8: R207.2, U29.H4, U30.11
GPIO0/ACCEL_INT9: R233.2, U33.H4, U34.11
GPIO1_J3_1: J10.2, U5.G4
GPIO1_J3_2: J3.2, U1.G4
GPIO1_J3_3: J16.2, U9.G4
GPIO1_J3_4: J22.2, U13.G4
GPIO1_J3_5: J28.2, U17.G4
GPIO1_J3_6: J34.2, U21.G4
GPIO1_J3_7: J40.2, U25.G4
GPIO1_J3_8: J46.2, U29.G4
GPIO1_J3_9: J52.2, U33.G4
GPIO3_J3_1: J10.5, U5.G5
GPIO3_J3_2: J16.5, U9.G5
GPIO3_J3_3: J22.5, U13.G5
GPIO3_J3_4: J28.5, U17.G5
GPIO3_J3_5: J3.5, U1.G5
GPIO3_J3_6: J34.5, U21.G5
GPIO3_J3_7: J40.5, U25.G5
GPIO3_J3_8: J46.5, U29.G5
GPIO3_J3_9: J52.5, U33.G5
GPIO4/CAMERA_Y1: J9.18, U5.D9
GPIO4/CAMERA_Y2: J15.18, U9.D9
GPIO4/CAMERA_Y3: J21.18, U13.D9
GPIO4/CAMERA_Y4: J6.18, U1.D9
GPIO4/CAMERA_Y5: J27.18, U17.D9
GPIO4/CAMERA_Y6: J33.18, U21.D9
GPIO4/CAMERA_Y7: J39.18, U25.D9
GPIO4/CAMERA_Y8: J45.18, U29.D9
GPIO4/CAMERA_Y9: J51.18, U33.D9
GPIO5/CAMERA_Y1: J9.20, U5.E9
GPIO5/CAMERA_Y2: J15.20, U9.E9
GPIO5/CAMERA_Y3: J6.20, U1.E9
GPIO5/CAMERA_Y4: J21.20, U13.E9
GPIO5/CAMERA_Y5: J27.20, U17.E9
GPIO5/CAMERA_Y6: J33.20, U21.E9
GPIO5/CAMERA_Y7: J39.20, U25.E9
GPIO5/CAMERA_Y8: J45.20, U29.E9
GPIO5/CAMERA_Y9: J51.20, U33.E9
GPIO6/CAMERA_Y0: J6.19, U1.E8
GPIO6/CAMERA_Y1: J9.19, U5.E8
GPIO6/CAMERA_Y2: J15.19, U9.E8
GPIO6/CAMERA_Y3: J21.19, U13.E8
GPIO6/CAMERA_Y4: J27.19, U17.E8
GPIO6/CAMERA_Y5: J33.19, U21.E8
GPIO6/CAMERA_Y6: J39.19, U25.E8
GPIO6/CAMERA_Y7: J45.19, U29.E8
GPIO6/CAMERA_Y8: J51.19, U33.E8
GPIO7/CAM_XCLK: J6.13, U1.F9
GPIO7/CAM_XCLK1: J9.13, U5.F9
GPIO7/CAM_XCLK2: J15.13, U9.F9
GPIO7/CAM_XCLK3: J21.13, U13.F9
GPIO7/CAM_XCLK4: J27.13, U17.F9
GPIO7/CAM_XCLK5: J33.13, U21.F9
GPIO7/CAM_XCLK6: J39.13, U25.F9
GPIO7/CAM_XCLK7: J45.13, U29.F9
GPIO7/CAM_XCLK8: J51.13, U33.F9
GPIO8/CAMERA_Y1: J6.21, U1.F8
GPIO8/CAMERA_Y2: J9.21, U5.F8
GPIO8/CAMERA_Y3: J15.21, U9.F8
GPIO8/CAMERA_Y4: J21.21, U13.F8
GPIO8/CAMERA_Y5: J27.21, U17.F8
GPIO8/CAMERA_Y6: J33.21, U21.F8
GPIO8/CAMERA_Y7: J39.21, U25.F8
GPIO8/CAMERA_Y8: J45.21, U29.F8
GPIO8/CAMERA_Y9: J51.21, U33.F8
GPIO9/CAMERA_Y1: J9.22, U5.G7
GPIO9/CAMERA_Y2: J6.22, U1.G7
GPIO9/CAMERA_Y3: J15.22, U9.G7
GPIO9/CAMERA_Y4: J21.22, U13.G7
GPIO9/CAMERA_Y5: J27.22, U17.G7
GPIO9/CAMERA_Y6: J33.22, U21.G7
GPIO9/CAMERA_Y7: J39.22, U25.G7
GPIO9/CAMERA_Y8: J45.22, U29.G7
GPIO9/CAMERA_Y9: J51.22, U33.G7
GPIO10/CAMERA_DVDD_EN: R11.2, U1.G8, U3.3
GPIO10/CAMERA_DVDD_EN1: R47.2, U5.G8, U7.3
GPIO10/CAMERA_DVDD_EN2: R73.2, U9.G8, U11.3
GPIO10/CAMERA_DVDD_EN3: R99.2, U13.G8, U15.3
GPIO10/CAMERA_DVDD_EN4: R125.2, U17.G8, U19.3
GPIO10/CAMERA_DVDD_EN5: R151.2, U21.G8, U23.3
GPIO10/CAMERA_DVDD_EN6: R177.2, U25.G8, U27.3
GPIO10/CAMERA_DVDD_EN7: R203.2, U29.G8, U31.3
GPIO10/CAMERA_DVDD_EN8: R229.2, U33.G8, U35.3
GPIO11/MIC0: R21.1, U1.B5, U4.1
GPIO11/MIC1: R44.1, U5.B5, U8.1
GPIO11/MIC2: R70.1, U9.B5, U12.1
GPIO11/MIC3: R96.1, U13.B5, U16.1
GPIO11/MIC4: R122.1, U17.B5, U20.1
GPIO11/MIC5: R148.1, U21.B5, U24.1
GPIO11/MIC6: R174.1, U25.B5, U28.1
GPIO11/MIC7: R200.1, U29.B5, U32.1
GPIO11/MIC8: R226.1, U33.B5, U36.1
GPIO12/CAMERA_VSYNC: J6.7, U1.A7
GPIO12/CAMERA_VSYNC1: J9.7, U5.A7
GPIO12/CAMERA_VSYNC2: J15.7, U9.A7
GPIO12/CAMERA_VSYNC3: J21.7, U13.A7
GPIO12/CAMERA_VSYNC4: J27.7, U17.A7
GPIO12/CAMERA_VSYNC5: J33.7, U21.A7
GPIO12/CAMERA_VSYNC6: J39.7, U25.A7
GPIO12/CAMERA_VSYNC7: J45.7, U29.A7
GPIO12/CAMERA_VSYNC8: J51.7, U33.A7
GPIO13/CAMERA_PWDN: J6.8, R22.2, U1.B7
GPIO13/CAMERA_PWDN1: J9.8, R48.2, U5.B7
GPIO13/CAMERA_PWDN2: J15.8, R74.2, U9.B7
GPIO13/CAMERA_PWDN3: J21.8, R100.2, U13.B7
GPIO13/CAMERA_PWDN4: J27.8, R126.2, U17.B7
GPIO13/CAMERA_PWDN5: J33.8, R152.2, U21.B7
GPIO13/CAMERA_PWDN6: J39.8, R178.2, U25.B7
GPIO13/CAMERA_PWDN7: J45.8, R204.2, U29.B7
GPIO13/CAMERA_PWDN8: J51.8, R230.2, U33.B7
GPIO14/USER_BUTTON: D7.A, R9.1, S1.3, S1.4, U1.D7
GPIO14/USER_BUTTON1: D14.A, R36.1, S3.3, S3.4, U5.D7
GPIO14/USER_BUTTON2: D21.A, R62.1, S5.3, S5.4, U9.D7
GPIO14/USER_BUTTON3: D28.A, R88.1, S7.3, S7.4, U13.D7
GPIO14/USER_BUTTON4: D35.A, R114.1, S9.3, S9.4, U17.D7
GPIO14/USER_BUTTON5: D42.A, R140.1, S11.3, S11.4, U21.D7
GPIO14/USER_BUTTON6: D49.A, R166.1, S13.3, S13.4, U25.D7
GPIO14/USER_BUTTON7: D56.A, R192.1, S15.3, S15.4, U29.D7
GPIO14/USER_BUTTON8: D63.A, R218.1, S17.3, S17.4, U33.D7
GPIO15/CAMERA_RESET: J6.6, R10.1, U1.C7
GPIO15/CAMERA_RESET1: J9.6, R35.1, U5.C7
GPIO15/CAMERA_RESET2: J15.6, R61.1, U9.C7
GPIO15/CAMERA_RESET3: J21.6, R87.1, U13.C7
GPIO15/CAMERA_RESET4: J27.6, R113.1, U17.C7
GPIO15/CAMERA_RESET5: J33.6, R139.1, U21.C7
GPIO15/CAMERA_RESET6: J39.6, R165.1, U25.C7
GPIO15/CAMERA_RESET7: J45.6, R191.1, U29.C7
GPIO15/CAMERA_RESET8: J51.6, R217.1, U33.C7
GPIO17/ACCEL_INT1: R26.2, U1.D3, U2.12
GPIO17/ACCEL_INT2: R52.2, U5.D3, U6.12
GPIO17/ACCEL_INT3: R78.2, U9.D3, U10.12
GPIO17/ACCEL_INT4: R104.2, U13.D3, U14.12
GPIO17/ACCEL_INT5: R130.2, U17.D3, U18.12
GPIO17/ACCEL_INT6: R156.2, U21.D3, U22.12
GPIO17/ACCEL_INT7: R182.2, U25.D3, U26.12
GPIO17/ACCEL_INT8: R208.2, U29.D3, U30.12
GPIO17/ACCEL_INT9: R234.2, U33.D3, U34.12
GPIO20/SWDCK: J5.4, R4.2, TP1.P$1, U1.G6
GPIO20/SWDCK1: J8.4, R28.2, TP8.P$1, U5.G6
GPIO20/SWDCK2: J14.4, R54.2, TP15.P$1, U9.G6
GPIO20/SWDCK3: J20.4, R80.2, TP22.P$1, U13.G6
GPIO20/SWDCK4: J26.4, R106.2, TP29.P$1, U17.G6
GPIO20/SWDCK5: J32.4, R132.2, TP36.P$1, U21.G6
GPIO20/SWDCK6: J38.4, R158.2, TP43.P$1, U25.G6
GPIO20/SWDCK7: J44.4, R184.2, TP50.P$1, U29.G6
GPIO20/SWDCK8: J50.4, R210.2, TP57.P$1, U33.G6
GPIO21/SWDIO: J5.2, R3.1, TP2.P$1, U1.F7
GPIO21/SWDIO1: J8.2, R29.1, TP9.P$1, U5.F7
GPIO21/SWDIO2: J14.2, R55.1, TP16.P$1, U9.F7
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

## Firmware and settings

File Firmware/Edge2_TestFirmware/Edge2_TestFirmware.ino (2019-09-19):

/* Author: Nathan Seidle
  Created: Septempter 19th, 2019
  License: MIT. See SparkFun Arduino Apollo3 Project for more information

  This example demonstrates the following:
    Activate 1.8V vreg
    Ping Accel
    Ping mics
    Twinkle LEDs
    Drive Qwiic pins
*/

#include <Wire.h>

#include "SparkFun_LIS2DH12.h"

SPARKFUN_LIS2DH12 accel; //Create instance of object

#define ACCEL_ADDRESS 0x19 //On the Edge and Edge2 the accelerometer is address 0x19

unsigned long lastTimeCheck = 0;

#define QWIIC_SCL 39
#define QWIIC_SDA 30

#define VDD_CAMERA 32
#define VDD_PDM 0 //Only available on v2.2 PCB and above
#define VDD_ACCEL 41 //Only available on v2.2 PCB and above

//-=-=-= Vars for PDM -=-=-=-

//Global variables needed for PDM library
#define pdmDataBufferSize 4096 //Default is array of 4096 * 32bit
uint32_t pdmDataBuffer[pdmDataBufferSize];

//Global variables needed for the FFT in this sketch
float g_fPDMTimeDomain[pdmDataBufferSize * 2];
float g_fPDMFrequencyDomain[pdmDataBufferSize * 2];
float g_fPDMMagnitudes[pdmDataBufferSize * 2];
uint32_t sampleFreq;

//Enable these defines for additional debug printing
#define PRINT_PDM_DATA 0
#define PRINT_FFT_DATA 0

#include <PDM.h> //Include PDM library included with the Aruino_Apollo3 core
AP3_PDM myPDM; //Create instance of PDM class

//Math library needed for FFT
#define ARM_MATH_CM4
#include <arm_math.h>

//-=-=-=- End Vars for PDM -=-=-=-

bool accelGood = false;
bool micGood = false;

void setup()
{
  Serial.begin(9600);
  Serial.println("SparkFun Accel Example");

  pinMode(LED_GREEN, OUTPUT);
  pinMode(LED_RED, OUTPUT);
  pinMode(LED_YELLOW, OUTPUT);
  pinMode(LED_BLUE, OUTPUT);
  digitalWrite(LED_GREEN, LOW);
  digitalWrite(LED_RED, LOW);
  digitalWrite(LED_YELLOW, HIGH);
  digitalWrite(LED_BLUE, HIGH);

  pinMode(VDD_CAMERA, OUTPUT);
  digitalWrite(VDD_CAMERA, HIGH); //Power up camera 1.8V regulator.

  //Normally we would not drive the SDA/SCL lines directly on the Qwiic connector (Wire)
  //but the test jig is just looking for continuity
  pinMode(QWIIC_SCL, OUTPUT);
  digitalWrite(QWIIC_SCL, LOW);
  pinMode(QWIIC_SDA, OUTPUT);
  digitalWrite(QWIIC_SDA, HIGH);

  pinMode(VDD_ACCEL, OUTPUT);
  digitalWrite(VDD_ACCEL, HIGH); //Power up accel. Only available on v2.2 PCB and above.

  Wire1.begin(); //Accel is on IOM3 and defined in the variant file as Wire1.

  //By default the SparkFun library uses Wire. We need to begin
  //with Wire1 on the Edge/Edge2.
  if (accel.begin(ACCEL_ADDRESS, Wire1) == false)
  {
    Serial.println("Accelerometer not detected. Are you sure you did a Wire1.begin()? Freezing...");
    while (1);
  }

  pinMode(VDD_PDM, OUTPUT);
  digitalWrite(VDD_PDM, HIGH); //Power up mics. Only available on v2.2 PCB and above.

  if (myPDM.begin() == false) // Turn on PDM with default settings
  {
    Serial.println("PDM Init failed. Are you sure these pins are PDM capable?");
    while (1);
  }
  Serial.println("PDM Initialized");

  printPDMConfig();

  myPDM.getData(pdmDataBuffer, pdmDataBufferSize); //This clears the current PDM FIFO and starts DMA
}

void loop()
{
  //Toggle LEDs and Qwiic pins
  if (millis() - lastTimeCheck > 1000)
  {
    lastTimeCheck = millis();

    if (digitalRead(LED_GREEN) == LOW)
    {
      digitalWrite(LED_GREEN, HIGH);
      digitalWrite(LED_RED, HIGH);
      digitalWrite(LED_YELLOW, LOW);
      digitalWrite(LED_BLUE, LOW);

      digitalWrite(QWIIC_SCL, HIGH);
      digitalWrite(QWIIC_SDA, LOW);
    }
    else
    {
      digitalWrite(LED_GREEN, LOW);
      digitalWrite(LED_RED, LOW);
      digitalWrite(LED_YELLOW, HIGH);
      digitalWrite(LED_BLUE, HIGH);

      digitalWrite(QWIIC_SCL, LOW);
      digitalWrite(QWIIC_SDA, HIGH);
    }
  }

  //Wait for new accel data
  while(accel.available() == false) ;

    float accelX = accel.getX();
    float accelY = accel.getY();
    float accelZ = accel.getZ();
    if (accelZ > 500.0) accelGood = true;
    
    float tempC = accel.getTemperature();

    Serial.print("Acc [mg]: ");
    Serial.print(accelX, 1);
    Serial.print(" x, ");
    Serial.print(accelY, 1);
    Serial.print(" y, ");
    Serial.print(accelZ, 1);
    Serial.print(" z, ");
    Serial.print(tempC, 1);
    Serial.print("C");

  //Wait for new PDM data
  while(myPDM.available() == false) ;

    noInterrupts();
    printLoudest();

    while (PRINT_PDM_DATA || PRINT_FFT_DATA);

    // Start converting the next set of PCM samples.
    myPDM.getData(pdmDataBuffer, pdmDataBufferSize);
    interrupts();

  if(accelGood && micGood) Serial.println(" Accel/Mic Good");
}

//*****************************************************************************
//
// Analyze and print frequency data.
//
//*****************************************************************************
void printLoudest(void)
{
  float fMaxValue;
  uint32_t ui32MaxIndex;
  int16_t *pi16PDMData = (int16_t *) pdmDataBuffer;
  uint32_t ui32LoudestFrequency;

  //
  // Convert the PDM samples to floats, and arrange them in the format
  // required by the FFT function.
  //
  for (uint32_t i = 0; i < pdmDataBufferSize; i++)
  {
    if (PRINT_PDM_DATA)
    {
      Serial.printf("%d\n", pi16PDMData[i]);
    }

    g_fPDMTimeDomain[2 * i] = pi16PDMData[i] / 1.0;
    g_fPDMTimeDomain[2 * i + 1] = 0.0;
  }

  if (PRINT_PDM_DATA)
  {
    Serial.printf("END\n");
  }

  //
  // Perform the FFT.
  //
  arm_cfft_radix4_instance_f32 S;
  arm_cfft_radix4_init_f32(&S, pdmDataBufferSize, 0, 1);
  arm_cfft_radix4_f32(&S, g_fPDMTimeDomain);
  arm_cmplx_mag_f32(g_fPDMTimeDomain, g_fPDMMagnitudes, pdmDataBufferSize);

  if (PRINT_FFT_DATA)
  {
    for (uint32_t i = 0; i < pdmDataBufferSize / 2; i++)
    {
      Serial.printf("%f\n", g_fPDMMagnitudes[i]);
    }

    Serial.printf("END\n");
  }

  //
  // Find the frequency bin with the largest magnitude.
  //
  arm_max_f32(g_fPDMMagnitudes, pdmDataBufferSize / 2, &fMaxValue, &ui32MaxIndex);

  ui32LoudestFrequency = (sampleFreq * ui32MaxIndex) / pdmDataBufferSize;

  if (PRINT_FFT_DATA)
  {
    Serial.printf("Loudest frequency bin: %d\n", ui32MaxIndex);
  }

  Serial.printf(" Loudest frequency: %d", ui32LoudestFrequency);

  if(ui32LoudestFrequency > 0) micGood = true;
}

//*****************************************************************************
//
// Print PDM configuration data.
//
//*****************************************************************************
void printPDMConfig(void)
{
  uint32_t PDMClk;
  uint32_t MClkDiv;
  float frequencyUnits;

  //
  // Read the config structure to figure out what our internal clock is set
  // to.
  //
  switch (myPDM.getClockDivider())
  {
    case AM_HAL_PDM_MCLKDIV_4: MClkDiv = 4; break;
    case AM_HAL_PDM_MCLKDIV_3: MClkDiv = 3; break;
    case AM_HAL_PDM_MCLKDIV_2: MClkDiv = 2; break;
    case AM_HAL_PDM_MCLKDIV_1: MClkDiv = 1; break;

    default:
      MClkDiv = 0;
  }

  switch (myPDM.getClockSpeed())
  {
    case AM_HAL_PDM_CLK_12MHZ:  PDMClk = 12000000; break;
    case AM_HAL_PDM_CLK_6MHZ:   PDMClk =  6000000; break;
    case AM_HAL_PDM_CLK_3MHZ:   PDMClk =  3000000; break;
    case AM_HAL_PDM_CLK_1_5MHZ: PDMClk =  1500000; break;
    case AM_HAL_PDM_CLK_750KHZ: PDMClk =   750000; break;
    case AM_HAL_PDM_CLK_375KHZ: PDMClk =   375000; break;
    case AM_HAL_PDM_CLK_187KHZ: PDMClk =   187000; break;

    default:
      PDMClk = 0;
  }

  //
  // Record the effective sample frequency. We'll need it later to print the
  // loudest frequency from the sample.
  //
  sampleFreq = (PDMClk / (MClkDiv * 2 * myPDM.getDecimationRate()));

  frequencyUnits = (float) sampleFreq / (float) pdmDataBufferSize;

  Serial.printf("Settings:\n");
  Serial.printf("PDM Clock (Hz):         %12d\n", PDMClk);
  Serial.printf("Decimation Rate:        %12d\n", myPDM.getDecimationRate());
  Serial.printf("Effective Sample Freq.: %12d\n", sampleFreq);
  Serial.printf("FFT Length:             %12d\n\n", pdmDataBufferSize);
  Serial.printf("FFT Resolution: %15.3f Hz\n", frequencyUnits);
}

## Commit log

2018-12-18 Adding board version number
    [SparkFun_TensorFlow_Ambiq_Apollo3.brd, SparkFun_TensorFlow_Ambiq_Apollo3.sch]
2018-12-19 Setting trace width/clearance to 5mil, via size to .2mm min
    [SparkFun_TensorFlow_Ambiq_Apollo3.brd, SparkFun_TensorFlow_Ambiq_Apollo3.sch]
2018-12-19 Checklist cleanup of schematic.
    [SparkFun_TensorFlow_Ambiq_Apollo3.brd, SparkFun_TensorFlow_Ambiq_Apollo3.sch]
2018-12-20 Adding 3x3 production panel and gerbers.
    [SparkFun_TensorFlow_Ambiq_Apollo3-Panel.GBL, SparkFun_TensorFlow_Ambiq_Apollo3-Panel.GBO, SparkFun_TensorFlow_Ambiq_Apollo3-Panel.GBP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]
2019-01-28 Adding v01 of Tensorflow
    [SparkFun_TensorFlow_Ambiq_Apollo3.brd, SparkFun_TensorFlow_Ambiq_Apollo3.sch]
2019-01-30 Adding v01 of production panel.
    [SparkFun_TensorFlow_Ambiq_Apollo3-Panel.GBL, SparkFun_TensorFlow_Ambiq_Apollo3-Panel.GBO, SparkFun_TensorFlow_Ambiq_Apollo3-Panel.GBP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]
2019-01-30 Removing old production files (x01)
    [SparkFun_TensorFlow_Ambiq_Apollo3-Panel.GBL, SparkFun_TensorFlow_Ambiq_Apollo3-Panel.GBO, SparkFun_TensorFlow_Ambiq_Apollo3-Panel.GBP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]
2019-02-07 Disconnecting DVDD from VDD, adding test points.
    [SparkFun_TensorFlow_Ambiq_Apollo3.brd, SparkFun_TensorFlow_Ambiq_Apollo3.sch]
2019-02-12 Changes post-design review
    - Silkscreen on back
    - Add auto-reset diode
    - Tuck battery overpaste in under connector
    [SparkFun_TensorFlow_Ambiq_Apollo3.brd, SparkFun_TensorFlow_Ambiq_Apollo3.sch]
2019-02-12 Adding v01 Production panel.
    [SparkFun_TensorFlow_Ambiq_Apollo3-Panel.GBL, SparkFun_TensorFlow_Ambiq_Apollo3-Panel.GBO, SparkFun_TensorFlow_Ambiq_Apollo3-Panel.GBP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]
2019-02-12 Adding production ID's to all part numbers.
    [SparkFun_TensorFlow_Ambiq_Apollo3.brd, SparkFun_TensorFlow_Ambiq_Apollo3.sch]
2019-02-12 Change to 100x gain with 1M ohm resistors for mics
    [SparkFun_TensorFlow_Ambiq_Apollo3.brd, SparkFun_TensorFlow_Ambiq_Apollo3.sch]
2019-02-25 Change Mic gain to 75x
    This is Pete's requested final gain value
    [SparkFun_TensorFlow_Ambiq_Apollo3.brd, SparkFun_TensorFlow_Ambiq_Apollo3.sch]
2019-03-05 Updating components to SparkFun ibraries
    [SparkFun_TensorFlow_Ambiq_Apollo3.brd, SparkFun_TensorFlow_Ambiq_Apollo3.sch]
2019-03-05 Continue adding parts from SparkFun library
    [SparkFun_TensorFlow_Ambiq_Apollo3.brd, SparkFun_TensorFlow_Ambiq_Apollo3.sch]
2019-03-05 Finish converting parts to SparkFun library
    [SparkFun_TensorFlow_Ambiq_Apollo3.brd, SparkFun_TensorFlow_Ambiq_Apollo3.sch]
2019-05-20 Moving designators for asm sheet
    [SparkFun_TensorFlow_Ambiq_Apollo3.brd, SparkFun_TensorFlow_Ambiq_Apollo3.sch]
2019-05-22 Change to module layout
    [SparkFun_TensorFlow_Ambiq_Apollo3.brd, SparkFun_TensorFlow_Ambiq_Apollo3.sch]
2019-05-22 Moving TP to align with jig.
    [SparkFun_TensorFlow_Ambiq_Apollo3.brd]
2019-05-22 Update silk
    [SparkFun_TensorFlow_Ambiq_Apollo3.brd, SparkFun_TensorFlow_Ambiq_Apollo3.sch]
2019-05-22 Invert JTAG connector
    [SparkFun_TensorFlow_Ambiq_Apollo3.brd, SparkFun_TensorFlow_Ambiq_Apollo3.sch]
2019-07-01 Add panel files
    [SparkFun_TensorFlow_Ambiq_Apollo3-Panel.GBL, SparkFun_TensorFlow_Ambiq_Apollo3-Panel.GBO, SparkFun_TensorFlow_Ambiq_Apollo3-Panel.GBP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]
2019-07-02 Reroute camera interface to match himax spec
    [SparkFun_TensorFlow_Ambiq_Apollo3.brd, SparkFun_TensorFlow_Ambiq_Apollo3.sch]
2019-07-03 Move MCLK to PWM pin.
    [SparkFun_TensorFlow_Ambiq_Apollo3.brd, SparkFun_TensorFlow_Ambiq_Apollo3.sch]
2019-07-25 Move mics to 2cm spacing. Re-wire camera connection.
    [SparkFun_TensorFlow_Ambiq_Apollo3.brd, SparkFun_TensorFlow_Ambiq_Apollo3.sch]
2019-07-25 Move cap to avoid silk
    [SparkFun_TensorFlow_Ambiq_Apollo3.brd, SparkFun_TensorFlow_Ambiq_Apollo3.sch]
2019-07-25 Adding panel files for v2.1
    [SparkFun_TensorFlow_Ambiq_Apollo3-Panel.GBL, SparkFun_TensorFlow_Ambiq_Apollo3-Panel.GBO, SparkFun_TensorFlow_Ambiq_Apollo3-Panel.GBP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]
2019-08-17 Change bootload circuit to use 0.1uF/220k standards.
    [SparkFun_TensorFlow_Ambiq_Apollo3.brd, SparkFun_TensorFlow_Ambiq_Apollo3.sch]
2019-08-20 Move parts to fill gap left by DNP resistor removal. Change text in sch from Apollo3 to Artemis.
    [SparkFun_TensorFlow_Ambiq_Apollo3.brd, SparkFun_TensorFlow_Ambiq_Apollo3.sch]
2019-09-06 Add DNP resistor back to design to match production boards.
    [SparkFun_TensorFlow_Ambiq_Apollo3.brd, SparkFun_TensorFlow_Ambiq_Apollo3.sch]
2019-09-20 Update for Edge 2
    - Update Readme and Links
    - Add board dimensions for Edge 2
2019-10-24 regenerate and rename schematic pdf

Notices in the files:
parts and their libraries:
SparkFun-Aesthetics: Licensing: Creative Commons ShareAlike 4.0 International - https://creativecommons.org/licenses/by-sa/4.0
